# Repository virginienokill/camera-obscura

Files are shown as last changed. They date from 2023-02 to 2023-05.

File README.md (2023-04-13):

# Camera Obscura

### travail en cours

*Camera Obscura* est un projet de théâtre optique itinérant de la Cie Nokill dont la première est prévue pour l'été 2024. 

Sur ce site nous rassemblons au fur et à mesure de la création, tous les contenus artistiques et techniques qui nous sont utiles. 

Même si à la base cette documentation est un outil de travail personnel, nous avons décidé de la mettre à disposition de toute personne intéressée par ce projet.

- [Dossier de création](contenu/dossier/dossier-camera-obscura-2024-web.pdf), télécharger le dossier en pdf.
- [Prototypes](contenu/prototypes), liste des chambres construites pendant la création.
- [Écriture](contenu/ecriture), textes, scenarios, découpages et références.
- [Technique](contenu/technique), questions et réponses concernant les differents défis techniques. 
- [Production](contenu/production.md), partenaires du projet et calendrier des résidences.
- [Bibliographie](contenu/bibliographie.md), liens et documents utiles.
- [Todo](contenu/todo.md), bloc-notes des trucs à faire.
- [Présentation du projet](contenu/presentation-partenaires.md), à l’intention des partenaires techniques et scientifiques.
- [Media](contenu/media.md), liste de tous les media liés à la documentation de la création.

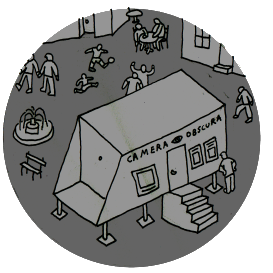
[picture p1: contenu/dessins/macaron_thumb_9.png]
Dessin de la remorque


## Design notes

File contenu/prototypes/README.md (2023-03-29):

# Les prototypes de chambres noires

D'ici, on peut accéder aux fiches des différents protos de chambres noires (camera obscura). On distingue 2 types de réalisations :
- Les chambres individuelles, pour 1 regardeur à la fois (00, 01, 02, 03). Concues au départ pour tester les principes optiques du projet final (05) qui accueillera le spectacle, elles peuvent être disposées dans l'espace public en libre accès.
- Les chambres collectives pour un groupe de regardeurs dont le nombre peut varier de six (04) à vingt (05).

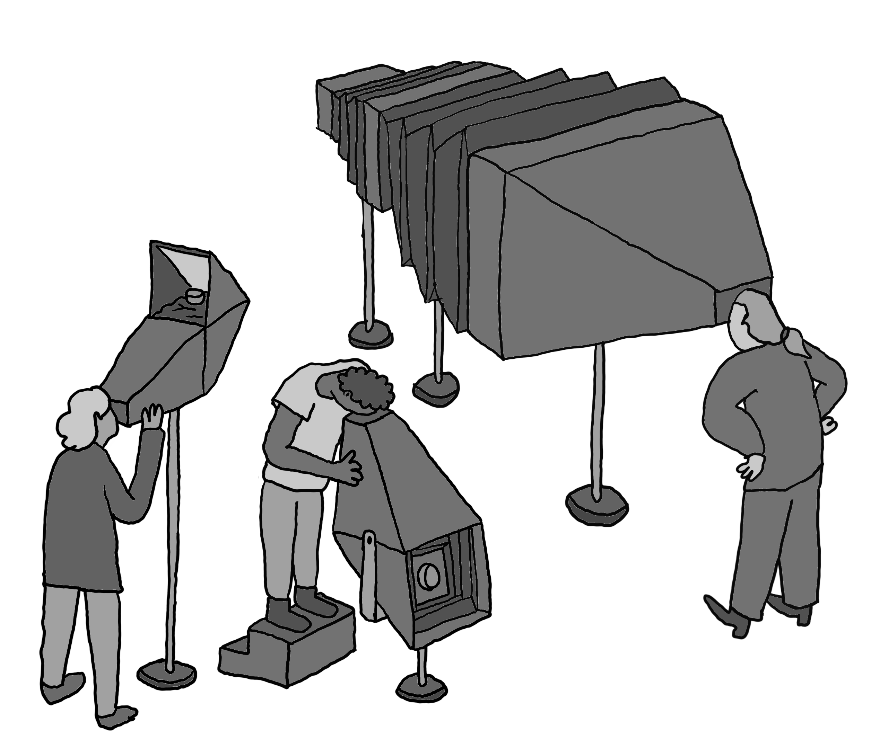
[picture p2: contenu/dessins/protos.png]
dessin de trois prototypes

*De gauche à droite, les cameras 01, 02 et 03*

## Chambres individuelles

- [Camera obscura 00 - Mini camera obscura](camera00.md)
- [Camera obscura 01 - Les yeux dans le dos](camera01.md)
- [Camera obscura 02 - Chambre à antotype](camera02.md)
- [Camera obscura 03 - Chambre grand format](camera03.md)

## Chambres collectives

- [Camera obscura 04 - Chambre sprinter](camera04.md)
- [Camera obscura 05 - Chambre remorque](camera05.md)

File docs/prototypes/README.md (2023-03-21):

Les prototypes de camera obscura
================================

D'ici, on peut accéder aux fiches des différents protos de camera obscura. On distingue 2 types de réalisations :
- Les cameras obscuras individuelles, pour 1 regardeur à la fois (00, 01, 02, 03). Concues au départ pour tester les principes optiques du projet final (05) qui accueillera le spectacle, elle peuvent être disposées dans l'espace public en libre accès.
- Les cameras obscuras collectives pour un groupe de regardeurs dont le nombre peut varier de six (04) à vingt (05).

dessin de trois prototypes
*De gauche à droite, les cameras 01, 02 et 03*

Les Protos
----------

- [Camera obscura 00 - Mini camera obscura](camera00.md)
- [Camera obscura 01 - Les yeux dans le dos](camera01.md)
- [Camera obscura 02 - Chambre à antotype](camera02.md)
- [Camera obscura 03 - Chambre grand format](camera03.md)
- [Camera obscura 04 - Chambre sprinter](camera04.md)

Le Projet final
---------------

- [Camera obscura 05 - Chambre remorque](camera05.md)

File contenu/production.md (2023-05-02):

# Partenaires

Coproducteurs :

- MIMA
- LE PARVIS
- QUAI DES SAVOIRS

Soutiens :

- LE KIWI / ARTO
- LE PERISCOPE
- RUE D'ÉTÉ
- CIRCA
- SCÈNES CROISÉES DE LOZÈRE
- ASSOCIATION DES CLOUS

Interlocuteurices :

- Cie Titanos
- Arnaud Vidal
- Jérémie Dain
- Eric Amblard
- Evelyne Salançon
- Gérard Tayeb
- Juan P. Martínez Pastor 

# Calendrier des résidences

## Résidences passées

### du 7/12/2022 au 14/12/2022 : Graulhet (81) - Nokill
- construction maquette "les yeux dans le dos"
- début construction chambre à anthotypes

### du 2/3/2023 au 4/3/2022 : Graulhet (81) - Nokill
- finitions chambre à anthotype
- début construction chambre grand format
- début construction double miroir

### du 6/3/2023 au 8/3/2022 : Toulouse (31) - QDS
- Améliorations protos
- Recherches autour du soufflet
- Documentation des protos
- Tests en extérieur

### du 1/4/2023 au 6/4/2023 : Graulhet (81) - Chez Pons et au Fablab de la MJC de Graulhet

- construction soufflets des cameras 2 et 3
- construction du prisme de miroirs en toit d'Amici
- début construction camera 4
- prise de contact avec le Fablab d'Airbus 
- Amélioration cameras 1 et 2
- Construction camera 3
- Tests en extérieur
- Documentation vidéo avec Mathieu

## Résidences à venir

### du 9/5/2023 au 12/5/2023 : Toulouse (31) - QDS
- Rencontre Airbus ?

### du 10/6/2023 au 18/6/2023 : Mirepoix (09) - Mima
- test camion

### en juillet 2023 (du 11 au 13 ou du 25 au 27) : Ramonville (31) - Arto
- test camion

### en été 2023 : Graulhet (81) - Nokill ou Marseille (13) - Nokill
- plans remorque 

### en automne 2023
Maxeville (Michto) ou accueil en Occitanie. 
- construction remorque

### du 30/10/2023 au 5/11/2023 : Assier (46) - Des clous
- écriture et aménagement remorque

### fin hiver/printemps 2024 (du 15 au 26 avril) : Auch (32) - Circa
- écriture et jeu

### printemps 2024 : Mende (48) - Scènes croisées de Lozère
- écriture et mise en scène

### printemps 2024 : Nimes (30) - Périscope
- écriture et mise en scène
- "Un atelier collectif autour de la création d'un court film qui utilise certaines des techniques en jeu dans la création en cours Camera Obscura. Les techniques en question se situant quelque part entre papier decoupé, théâtre d'ombre et lanterne magique."
### Juin juillet 2024 : Tarbes (65) - Le Parvis
- mise en scène

### du 23/7/2024 au 1/8/2024, Mirepoix (09) - Mima
- Finitions

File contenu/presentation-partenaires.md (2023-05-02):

# Camera Obscura
#### Fiche de présentation à l'intention des partenaires techniques et scientifiques.

*Camera Obscura* est un projet de théâtre optique itinérant dont la première est prévue pour l'été 2024.

<div style="display:flex;flex-direction:row;flex-wrap:wrap;">
illustration camera obscura
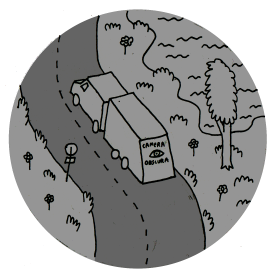
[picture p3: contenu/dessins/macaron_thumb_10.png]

</div>

## En résumé

Une salle de cinéma est posée dans l'espace public, une vingtaine de spectateurs s'y installent, la salle est plongée dans le noir et le public assiste à la projection d'un court-métrage d'une vingtaine de minutes.

La particularité de ce film est qu'il est produit sans pellicule, ni vidéo, ni électricité, et qu'il n'utilise comme énergie que celle du soleil et des comédiens.

<div style="display:flex;flex-direction:row;flex-wrap:wrap;">
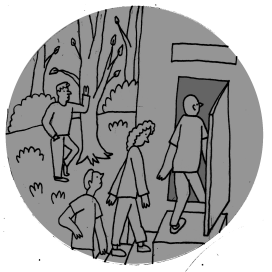
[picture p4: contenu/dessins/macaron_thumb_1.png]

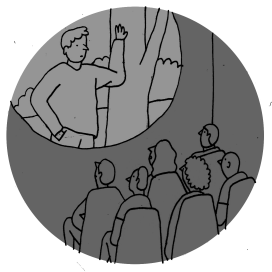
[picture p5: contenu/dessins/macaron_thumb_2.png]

</div>

Les images sont des captations du monde extérieur qui transitent par un dispositif optique fait d'objectifs, de prismes et de miroirs. Les sons et la musique sont produits et interprétés en direct grâce à un ensemble d'instruments acoustiques et mécaniques.

L’enjeu principal de cette création est donc de créer l’illusion de la projection d’un film et de reproduire les codes et les formes du cinéma, sans en utiliser la technologie.

Cette démarche s'inscrit à la fois dans une idée de sobriété énergétique et dans la volonté de créer une esthétique et une expérience unique.

## Défis techniques

Ce projet s'accompagne d'un grand nombre de défis techniques dans des domaines variés :
- Comment afficher une image [lumineuse](technique/luminosite.md) de [grande dimension](technique/calage.md) sans autre source de lumière que le soleil dans un véhicule transformé en salle de cinéma itinérante ?
- Comment [redresser une image](technique/renversement.md) naturellement renversée par son passage à travers un objectif ?
- Comment maintenir une [température supportable](technique/isolation.md) et assurer un renouvellement de l'air dans une remorque exposée au soleil sans apport extérieur d'énergie ?
- Comment servir des popcorns aux spectateurs, sans utiliser ni gaz ni électricité pour les cuire ?
- Comment donner l'[illusion d'un son "cinéma"](technique/son.md) en se limitant à des systèmes acoustiques ?
- Comment construire une [salle de cinéma](prototypes/camera05.md) légère, durable, compacte et mobile adaptée à l'accueil du public ?

Pour relever ces défis, nous cherchons activement des partenaires : des interlocuteurs pour la conception, mais aussi des lieux et des moyens de fabrication, et des circuits d'achat ou de récupération de matériel.

<div style="display:flex;flex-direction:row;flex-wrap:wrap;">
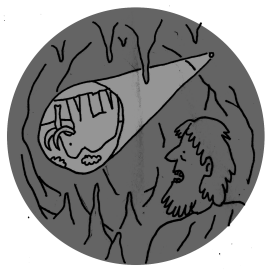
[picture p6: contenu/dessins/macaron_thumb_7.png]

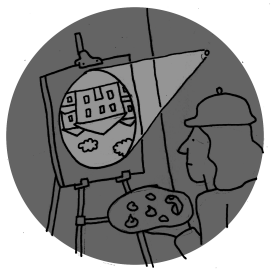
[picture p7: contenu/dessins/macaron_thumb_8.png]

</div>

## La compagnie Nokill

*Camera Obscura* sera le cinquième spectacle de notre compagnie. Dans les spectacles précédents dont les teasers et les descriptions sont disponibles sur [le site de la compagnie Nokill](http://cienokill.fr/), nous convoquons régulièrement sur scène des dispositifs techniques qui nous servent de supports pour raconter des histoires, des robots dans [*Turing Test*](http://turing-test.cienokill.fr/), des machines pré-cinématographiques dans [*L'Envol*](http://cienokill.fr/spectacles/lenvol/), des hologrammes dans [*Elektra*](http://cienokill.fr/spectacles/elektra/). *Camera Obscura* s'inscrit dans la continuité de cette démarche.

## La documentation du spectacle

Comme nous avons eu l'occasion de le faire pour [*Turing Test*](http://turing-test.cienokill.fr/), nous documentons l'intégralité du processus de création sur [un site dédié à *Camera Obscura*](https://camera-obscura.cienokill.fr/), vous pourrez y trouver du contenu concernant les différents aspects du spectacle (technique, artistique, production). Nous sommes aussi disponibles pour échanger [par mail](http://cienokill.fr/contact/) ou en visio, pour répondre à vos questions et vous parler du projet plus en détail.

<div style="display:flex;flex-direction:row;flex-wrap:wrap;">
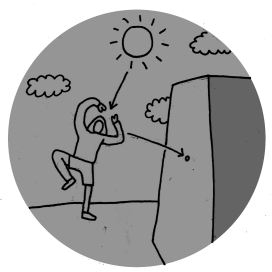
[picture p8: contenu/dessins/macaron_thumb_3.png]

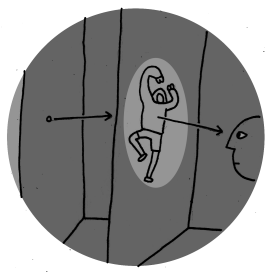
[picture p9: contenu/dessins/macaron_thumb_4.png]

</div>

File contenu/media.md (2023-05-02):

# Media

Cette page rassemble tous les medias liés à la documentation de la création. Ce sont les images, vidéos, etc. utilisées dans les différentes pages du site.

# Vidéos

Les vidéos sont hébergées sur Vimeo et rassemblées dans [un showcase nommé Camera Obscura](https://vimeo.com/showcase/10324493)

<div style='padding:56.25% 0 0 0;position:relative;'>
    <iframe src='https://vimeo.com/showcase/10324493/embed' allowfullscreen frameborder='0' style='position:absolute;top:0;left:0;width:100%;height:100%;'></iframe>
</div>

# Images

Les images sont réparties dans 4 dossiers. Elles sont hébergées sur le git. Les images en bitmap (non vectorielles) sont compressées pour alléger le site.

## Photos

le dossier [`photos/`](https://github.com/LeonLenclos/camera-obscura/tree/main/contenu/photos) contient les photos prises pendant la création.

{% include gallery.html folder="/contenu/photos/" %}

## Plans

le dossier [`plans/`](https://github.com/LeonLenclos/camera-obscura/tree/main/contenu/plans) contient les dessins techniques, patrons et plans utiles pendant la création.

{% include gallery.html folder="/contenu/plans/" %}

## Dessins

le dossier [`dessins/`](https://github.com/LeonLenclos/camera-obscura/tree/main/contenu/dessins) contient les dessins non-techniques et les illustrations.

{% include gallery.html folder="/contenu/dessins/" %}

## Img

le dossier [`img/`](https://github.com/LeonLenclos/camera-obscura/tree/main/contenu/img) contient toutes les images qui n'entrent pas dans les catégories précédentes, notamment les gif animés et les montages photos.

{% include gallery.html folder="/contenu/img/" %}

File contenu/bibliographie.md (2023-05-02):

# Liens

## Théorie

- [Schema interactifs d'optique géométrique](https://phyanim.sciences.univ-nantes.fr/optiqueGeo/index.php)
- [chaîne youtube de photo avec pas mal de contenus intéressants](https://youtube.com/@PhotoGraal)
- [geogebra](https://www.geogebra.org/calculator/hahmryyn)
- [logiciel (payant) pour créer des optiques](https://www.zemax.com/)
- [bouquins théoriques](https://www.babelio.com/livres/Houard-Optique/898680)

## Gramophone

- [Vidéo à propos du HMV 102](https://www.youtube.com/watch?v=AYn7aZZBMRA)

## Soufflets

- [Tuto détaillé général](https://www.galerie-photo.com/construire-soufflet-chambre-photo.html)
- [Tuto plus précis](http://www.disactis.com/soufflet/soufflet.php)
- [Tuto de monsieur Smets](https://docplayer.fr/12405417-Fabriquez-votre-soufflet.html)
- [Article de blog avec photos HD d'un vieux soufflet](https://delalumieredanslatelier.blogspot.com/2019/06/appareil-photo-soufflet-marque-nagel-n.html)

## Animation 

- [Terry Gilliam, cutout anim](https://youtu.be/KOqcHCEqO1k)

## Photo très grand format

- [Article sur des photographes très grand format](https://fstoppers.com/diy/photographer-creates-gigantic-ultra-large-format-digital-camera-571295)
- [Article de blog sur l'ultra-grand format](https://photographylife.com/ultra-large-format-cameras)
- [Définition de process lens discutée sur un forum de photo](https://www.photo.net/forums/topic/48909-what-is-a-process-lens/)
- [John Chiara photographe qui a une CO remorque pour faire du très grand format](https://www.johnchiara.com/films)

## Objectifs très grands formats / process lens

- [Doc technique détaillée sur les objectifs grands formats de Rodenstock](http://www.dmin-dmax.fr/chambre/archives_techniques/rodenstock_2000.html)

## Sténopé 

- [Tuto détaillé sur la photo au sténopé](https://galerie-photo.com/stenope.html)
- [Video stenopé numérique](https://www.youtube.com/watch?v=yWew2kOWTiA)

## Papier inversible 

- [Discussion autour du papier inversible sur un forum de photo ](http://www.galerie-photo.info/forumgp/read.php?3,239522)
- [DIRECT POSITIVE PAPER harman chez Ilford](https://www.ilfordphoto.com/harman-direct-positive-paper-roll)
- [direct positiv paper, différentes refs (eshop)](https://www.macodirect.de/en/paper/direct-positive-papers/)

## Camera obscura

- [Camera Obscura & World of Illusions , un musée à Édinburgh](https://www.camera-obscura.co.uk/attractions/the-camera-obscura)
- [Site très riche à propos de la CO par un restaurateur/créateur de CO](http://www.camera-obscura.org.uk/Camera_Obscura/Welcome.html)
- [Thomas Mezzanotte, artiste ayant notamment construit une CO dans une sorte de tente](https://thomas-mezzanotte.squarespace.com/)
- [Double CO sur un bateau sur le danube](https://olafureliasson.net/artwork/camera-obscura-fuer-die-donau-2004/)
- [CO sur une plage vers San Fransisco](https://youtu.be/qvwpDIlN25o)

## Miroirs caustiques

- [Rayform, fabriquant de miroirs caustiques](https://rayform.ch/)
- [Vidéo à propos des miroirs caustiques de rayform](https://www.youtube.com/watch?v=wk67eGXtbIw)

## True mirrors

- [Prisme en toit d'Amici](https://fr.wikipedia.org/wiki/Prisme_en_toit_d%27Amici)
- [La boutique](https://store.truemirror.com/)
- [La vidéo où le createur dit qu'il utilise des first surface mirror](https://www.youtube.com/watch?v=oHeOf9MZ49o)
- [la vidéo du mec là](https://www.youtube.com/watch?v=x2owiSx0biU)

## First surface mirror

- [How to Make a Front Surface Mirror (Quick & Easy Techniques)](https://medium.com/geekculture/how-to-make-a-front-surface-mirror-quick-easy-techniques-c1ba3ecf6347)
- [FSM (Fournisseur)](https://firstsurfacemirror.com/)

## prismes

- [tuto prisme eau ](https://www.instructables.com/Optical-Water-Prism/)

## Lanternes magiques

- [Lanternes magiques](https://en.wikipedia.org/wiki/Magic_lantern)
- [petit Doc en anglais](https://youtu.be/w1XkqtzLfKo)

## Historique

- [Objectif de CO avec prisme intégré 18e sciècle :](http://www.niepce-daguerre.com/objectif_de_camera_obscura.html)

## Antotypes

- [Anthotypes: explore the darkroom in your garden - Le livre de ref](http://leonlenclos.net/pro/pirate/anthotypes-explore-the-darkroom-in-your-garden-and-make-photographs-using-plants-1466261005-9781466261006_compress.pdf)
- [Recette à base d'épinard](http://wiki.scienceamusante.net/index.php/Les_anthotypes)
- [Le végétal est photographie (Mémoire)](https://www.esam-c2.fr/IMG/UserFiles/docs/memoires/2017_pelletier_marieve.pdf)
- [Mary Somerville, inventeuse oubliée de l'anthotypie ](https://en.wikipedia.org/wiki/Mary_Somerville)

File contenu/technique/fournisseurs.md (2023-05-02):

## Optiques, objectifs, prismes, verre

- [Camley](www.camleyphotographic.com/)
- [Coprover](https://www.coprover.fr/)
- [bonfoton](https://bonfoton.com/products/bonfoton-camera-obscura-lens)
- [amazing camera obscura](http://www.amazingcameraobscura.co.uk/shop.htm)
- [truemirror](https://store.truemirror.com/collections/all?page=1)
- [bohroptics](http://bohroptics.com/en)

## Ecran, tissus, tulle
- [Showtex](https://www.showtex.com/fr/produits/ecrans-de-projection?page=1)
- [Teviloj](https://www.azur-scenic.com/produit/retro-translucide-depoli/)

## Carton
- [hermet](https://www.hermet.fr/)

## Peinture
- [adaptaville](https://www.adaptaville.fr/peinture-anti-chaleur-toit)

## Remorque
- [rouergue-remorque](https://www.rouergue-remorque.com/remorque/remorque-bw-tiny-house-ch-600-2/)

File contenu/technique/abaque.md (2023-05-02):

Pour le Apo-Nikkor 610mm posé contre la vitre à l'intérieur de la CO

| Distance Objet-Vitre | Distance Vitre-Image |
|---|---|
| 70 cm | 320 cm |
| 100 cm | 155 cm |
| 200 cm | 91 cm |
| 800 cm | 70 cm |
| infini | 68 cm |

Pour le Rotenstock 360mm posé contre la vitre à l'intérieur de la CO

| Distance Objet-Vitre | Distance Vitre-Image |
|---|---|
| 40 cm | 172 cm |
| 70 cm | 72 cm |
| 100 cm | 57 cm |
| 200 cm | 46 cm |
| 800 cm | 41 cm |
| infini | 39 cm |

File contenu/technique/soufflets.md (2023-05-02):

# Les soufflets

Pour effectuer la mise au point et lorsque l'on change de focale, il faut changer la distance entre l'écran et l'optique.
Or, quelque soit la position de l'optique par rapport à l'écran, il faut que la chambre reste hermétique à la lumière.

Pour concilier étanchéité du dispositif et possibilité varier la position relative des deux parties,
la solution traditionnellement utilisée pour les chambres noires photographiques (mais aussi pour les accordéons et les autobus articulés) est celle du soufflet.

Bien que le choix du soufflet vienne apporter une solution très satisfaisante au problème décrit ci-dessus, il apporte aussi son lot de soucis :
- Le patron d'un soufflet est difficile à dessiner.
- Le choix des matériaux est délicat (robustesse, souplesse, étanchéité, couleur)
- La construction d'un soufflet est chronophage.

<div style="padding-bottom: 56.25%; max-width: 100%; position: relative;"><iframe src="https://player.vimeo.com/video/816255116?title=0&portrait=0&byline=0" width="800px" height="450px" style="position: absolute; top: 0px; left: 0px; width: 100%; height: 100%;" frameborder="0"></iframe></div>

*Timelapse de la construction d'un soufflet pour la [camera 03](../prototypes/camera03.md)*

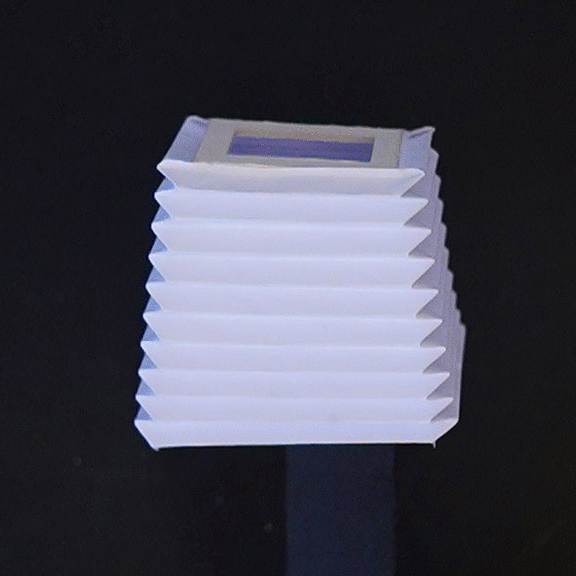
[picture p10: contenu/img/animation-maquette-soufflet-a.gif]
animation maquette soufflet

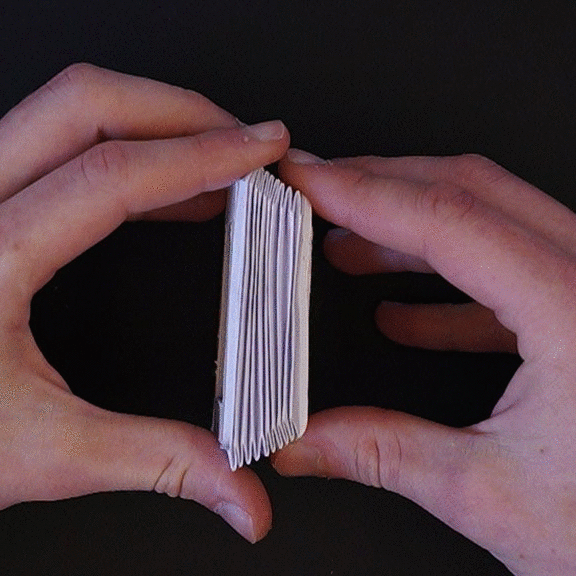
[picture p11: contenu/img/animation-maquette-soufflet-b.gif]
animation maquette soufflet


*Maquette de soufflet en papier*

## Processus de fabrication

### Dessiner un soufflet

On s'intéresse ici à la construction de soufflets "coniques" et "rectangulaires".

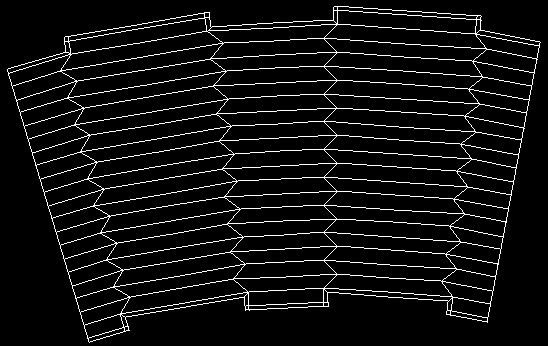
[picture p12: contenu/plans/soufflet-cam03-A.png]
patron d'un soufflet


*Exemple de patron d'un soufflet*

### Préparation

Choix à faire avant de commencer :

- taille du grand cadre
- taille du petit cadre (côté objectif)
- largeur des plis
- nombre de plis
- La manière dont le soufflet est collé au grand cadre et au petit cadre.

Pour la largeur des plis on choisit en général 100mm ou 50mm. Puisque le soufflet est conique les plis mesureront une fois sur deux un peu plus et une fois sur deux un peu moins que la valeur choisie. Cette valeur est néanmoins très importante pour dessiner le soufflet.

Le nombre de plis déterminera la longueur du soufflet minimum et maximum.

Dans le cas d'un soufflet très peu conique la longueur du soufflet ouvert au max sera environ `nombre de plis × largeur des plis × 1/2`

La longueur du soufflet fermé au max sera environ `nombre de plis × épaisseur du carton × 2.5`

Pour coller le soufflet à son support, trois solutions :

1. Coller à l'extérieur du cadre
2. Coller à l'intérieur du cadre
3. Coller à plat

**Attention : il est possible qu'une erreur se soit glissée dans les instructions concernant les collages 2 et 3**

Sur le dessin ci-dessous la longueur représentée par la flèche désigne ce qu'on appelle la taille du cadre. N.b. selon la manière de coller, ce que l'on désigne par taille du cadre peut faire référence à l'intérieur du soufflet (rectangle à travers lequel on regarde) ou faire référence à l'extérieur du soufflet (encombrement du soufflet quand il est plié)

schema collage soufflet

### Dessin

On va d'abord dessiner une arête du soufflet (un quart du soufflet) puis la dupliquer en appliquant des symétries axiales pour avoir le soufflet complet.

#### Tracer le pli en zigzag de l'arête

On commence par tracer deux traits verticaux espacés de la largeur d'un pli puis on trace un zigzag entre ces deux traits avec des angles de 90°. Ce zigzag a autant de sommets qu'il y aura de plis.

#### Tracer la médiane du pan de gauche

Soit C et D les deux extrémités du zigzag.

Tracer un cercle de centre C.
Si le trait du zigzag qui part de C va vers la gauche, le diamètre du cercle est : *1/2 × longueur du **petit** côté du **petit** cadre + largeur des plis*.
Sinon le diamètre est *1/2 × longueur du **petit** côté du **petit** cadre*.

Tracer un cercle de centre D.
Si le trait du zigzag qui part de D va vers la gauche, le diamètre du cercle est *1/2 × longueur du **petit** côté du **grand** cadre + largeur des plis*.
Sinon le diamètre est *1/2 × longueur du **petit** côté du **grand** cadre*

La médiane du pan de gauche est la tangeante extérieure à ces deux cercles qui passe à gauche des cercles. On la note droite d.

#### Tracer les plis du pan de gauche

Soit C' l'intersection de cette droite avec le cercle de centre C et D' l'intersection de cette droite avec le cercle de centre D.

les segments CC' et DD' sont le premier et le dernier pli du pan. CC' et DD' sont parallèles.

Tous les autres plis du pan peuvent désormais être tracés, ce sont les segments parallèles à CC' par chaque sommet du zigzag. on fait aller ces segments des sommets du zigzag à la droite d.

#### Reproduire ces étapes pour le pan de droite

Pour la médiane du pan de droite reproduire ces étapes symétriquement, mais en prenant en compte les longueurs des **grands** côtés des cadres.

#### Tracer les languettes aux extremités du soufflet.

pour la jonction cadre-soufflet se référer à ce [schema](/contenu/plans/collage-soufflet-patrons.png) en fonction de ce que l'on choisit comme manière de coller le soufflet au cadre. (En vert les plis extérieurs en cyan les plis intérieurs)

#### Dupliquer le tracé 

tracer la symétrie du dessin par la médiane du côté de gauche (droite d).

Puis tracer à nouveau la symétrie du dessin ainsi obtenu par la médiane du côté de droite.

## Construire un soufflet

Le soufflet sera réalisé avec un sandwich tissu-carton-skaï :
- Du tissu noir à l'intérieur
- Du carton 1mm pour la rigidité.
- Du skaï blanc à l'extérieur pour la fraicheur et l'étanchéité.

Le carton est coupé à la découpeuse laser : on creuse une gouttière de 2.5mm entre chaque pan et on laisse un petit raccord de 2.5mm tous les 200mm pour conserver la forme sans gêner le pliage.

La découpeuse laser du FabLab de Graulhet nous permet de découper des plaques en carton de 1000x700mm

Les fichiers pour la découpe seront fournis au format dxf.

Le sandwich est collé à la colle à reliure, temps de séchage = 24h.

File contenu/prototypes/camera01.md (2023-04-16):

#  Les Yeux Dans Le Dos

| prototype n° | 01 |
|---|---:|
| nom vernaculaire | Les Yeux Dans Le Dos |
| début construction | décembre 2022 |
| nombre de spectateur·ices | 1 |
| taille de l'image | 30×30 cm |
| distance de tirage min-max  | ? |
| dimensions exterieures | ? |
| objectif monté | Process lens Zeiss S-TESSAR 5,6/300 |

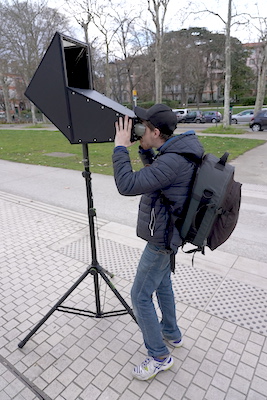
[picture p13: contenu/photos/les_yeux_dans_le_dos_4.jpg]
les_yeux_dans_le_dos_4


[une vidéo de test des Yeux dans le dos :](https://vimeo.com/cienokill/cameraobscura-proto01)

<div style="padding-bottom: 56.25%; max-width: 100%; position: relative;"><iframe src="https://player.vimeo.com/video/809841929?title=0&portrait=0&byline=0" width="800px" height="450px" style="position: absolute; top: 0px; left: 0px; width: 100%; height: 100%;" frameborder="0"></iframe></div>

## Description générale
En regardant à l'intérieur de cette camera obscura, on découvre une image à l'endroit d'environ 30 cm x 30 cm de ce qui est derrière nous.

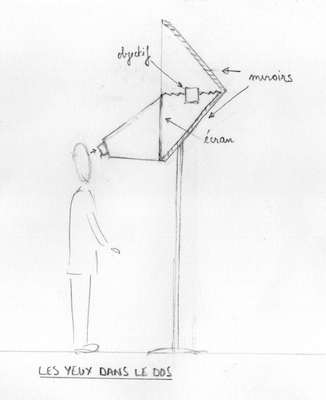
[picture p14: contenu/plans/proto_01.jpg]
proto_01

## Allure
Une boite noire de forme complexe est fixée sur un pied de projecteur. À hauteur d'yeux on trouve un viseur en forme de lunettes de protection.

## Matériaux
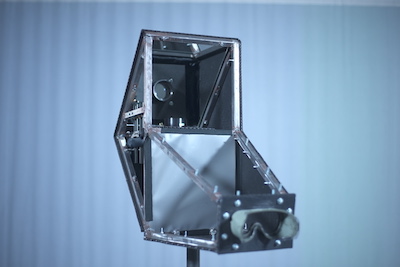
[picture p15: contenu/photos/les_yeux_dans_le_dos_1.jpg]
les_yeux_dans_le_dos_1


### Chassis
- Tube d'acier soudé (20 mm x 20 mm).

### Parois
- Panneau de plastique alvéolaire

### Écran
- Toile de rétroprojection (translucide/dépoli) tendue sur cadre acier

### Objectif
- Process lens Zeiss S-TESSAR 5,6/300

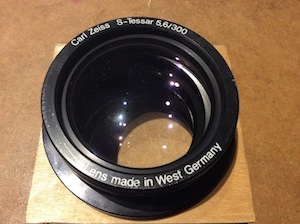
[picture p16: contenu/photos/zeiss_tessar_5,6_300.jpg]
zeiss_tessar_5,6_300


### accessoires
- L'objectif fixé sur un clamp coulisse sur 2 rails
- Un soufflet en tissu fixé entre la planchette et le chassis maintient l'obscurité.

## Évaluation des avantages et des inconvénients

### Avantages
- image très claire
- à l'endroit

### Inconvénients
- image relativement petite
- axe inversé

## Améliorations envisagées
- déport de point à l'extérieur pour faciliter le reglage de la position de l'objectif sur le rail.
- vitre de protection et pare-soleil pour protèger les miroirs et l'objectif.

## Moment envisagé pour la construction et/ou les améliorations
printemps 2023

## Détails de construction et description technique

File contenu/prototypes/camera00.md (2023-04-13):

#  Mini Camera obscura

| prototype n° | 00 |
|---|---:|
| nom vernaculaire |  Mini camera obscura |
| début construction | mars 2023 |
| nombre de spectateur·ices | 1 |
| taille de l'image | 4×4 cm |
| distance de tirage min-max  | ? |
| dimensions exterieures | ? |
| objectif monté | Helios 44-2 / 2/58mm |

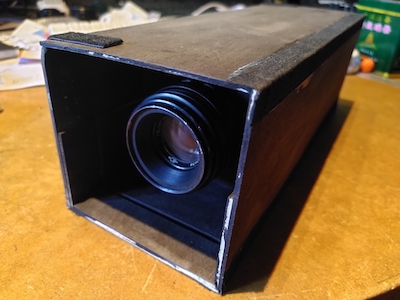
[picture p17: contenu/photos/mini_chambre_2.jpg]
mini_chambre_2


## Description générale
En regardant à l'intérieur de cette camera obscura, on découvre une image à l'endroit d'environ 4 cm x 4 cm de ce qui est devant nous.

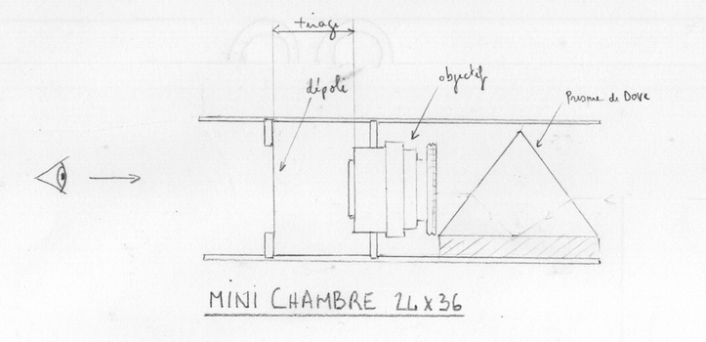
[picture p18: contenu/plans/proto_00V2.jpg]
proto_0


## Allure
Une boite noire de forme parallélépipédique. L'image est projetée sur un dépoli à l'arrière du tube. Un prisme de Dove est placé devant l'objectif.

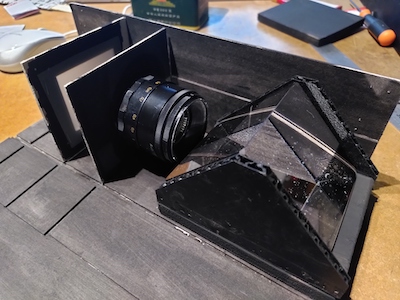
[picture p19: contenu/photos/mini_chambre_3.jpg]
mini_chambre_3

## Matériaux

### Parois
- Carton-bois

### Écran
- Toile de rétroprojection (translucide/dépoli) tendue sur cadre acier

### Objectif
- objectif 24x36 monture M42 (Helios 44-2 / 2/58mm) 

### Accessoires
- L'objectif et le dépoli sont fixés sur des planchettes maintenues dans des rigoles.

## Évaluation des avantages et des inconvénients

### Avantages
- très léger
- parfait pour des tests

### Inconvénients
- image petite et tronquée
## Améliorations envisagées

## Moment envisagé pour la construction et/ou les améliorations
printemps 2023

## Détails de construction et description technique

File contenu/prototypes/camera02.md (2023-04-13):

#  Chambre à Antotype

| prototype n° | 02 |
|---|---:|
| nom vernaculaire | Chambre à Antotype |
| début construction | décembre 2022 |
| nombre de spectateur·ices | 1 |
| taille de l'image | 50×50 cm |
| distance de tirage min-max  | environ 35-55cm |
| dimensions exterieures | ? |
| objectif monté | Process lens APO RONAR RODENSTOCK 9/360 mm |

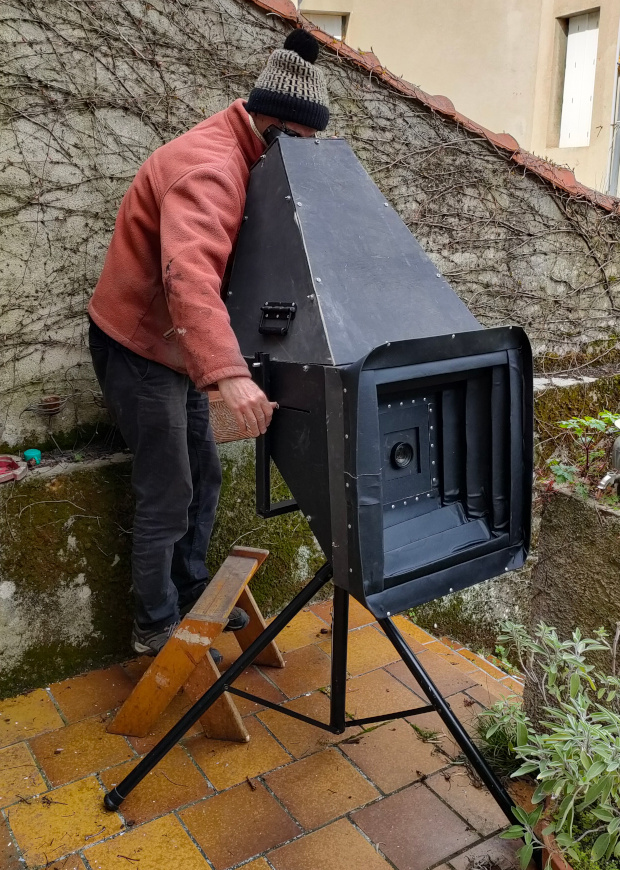
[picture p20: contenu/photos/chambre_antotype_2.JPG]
chambre_anthotype_1


## Description générale

En regardant dans le viseur situé au dessus de cette camera obscura, on découvre une image à l'endroit d'environ 50 cm x 50 cm de ce qui est devant nous.

L'écran est amovible et peut être remplacé par une plaque sur laquelle on aura disposé un papier photo-sensible type antotype.

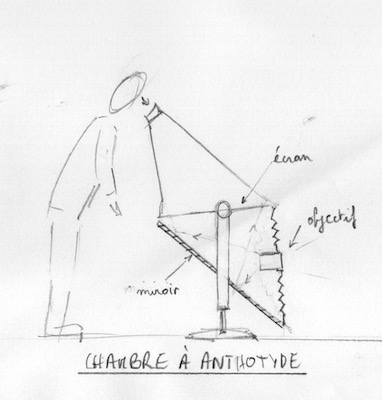
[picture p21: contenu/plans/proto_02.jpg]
proto_02


## Allure

Une boite noire de forme complexe est fixée sur un pied de projecteur. La forme évoque les chambres moyen-format type rolleiflex. Sur le dessus, on trouve un viseur en forme de lunettes de protection. À l'avant, un soufflet en skaï noir.

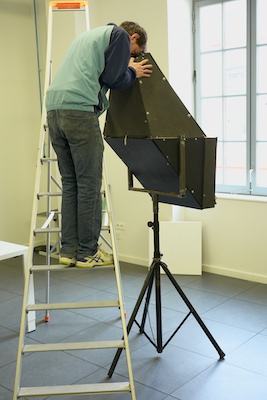
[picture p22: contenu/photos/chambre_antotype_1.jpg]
chambre_anthotype_1


## Matériaux

### Chassis
- Tube d'acier soudé (20 mm x 20 mm).

### Parois
- Panneau de plastique alvéolaire et contreplaqué 5 mm

### Écran
- Toile de rétroprojection (translucide/dépoli) tendue sur cadre acier

### Objectif
- Process lens APO RONAR RODENSTOCK 9/360 mm

### Accessoires
- La planchette de l'objectif est montée sur un rail Igus. Sur le côté exterieur de la chambre, une vis permet de régler la mise au point en entrainant la planchette.
- Un soufflet entre la planchette et le chassis maintient l'obscurité dans la boite.

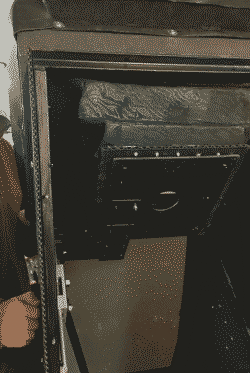
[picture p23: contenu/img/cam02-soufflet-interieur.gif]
animation soufflet


*Vue interieur du mécanisme de réglage de mise au point*

## Évaluation des avantages et des inconvénients

### Avantages
- image dans l'axe
- à l'endroit

### Inconvénients
- visée par le dessus
- peu clair

## Améliorations envisagées
- peinture du chassis
- vitre de protection et pare-soleil
- fixation des lunettes
- achat objectif plus lumineux

## Moment envisagé pour la construction et/ou les améliorations
printemps 2023

## Détails de construction et description technique

cotes proto02

### Soufflet

- [Patron soufflet en dxf](/contenu/plans/soufflet-cam02.dxf)
- [Patron soufflet en pdf pour aperçu](/contenu/plans/soufflet-cam02.pdf)

cotes :

- Grand cadre : 528mm x 488mm (collage interieur)
- Petit cadre : 220mm x 220mm (collage contre)
- Largeur plis : 50mm
- nombre de plis : 10

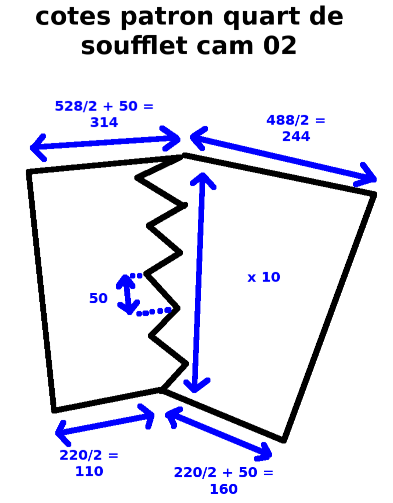
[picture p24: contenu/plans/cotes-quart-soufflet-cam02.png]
cotes soufflet


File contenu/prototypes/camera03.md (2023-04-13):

#  Chambre grand format

| prototype n° | 03 |
|---|---:|
| nom vernaculaire | Chambre grand format |
| début construction | mars 2023 |
| nombre de spectateur·ices | 1 |
| taille de l'image | 100×73 cm |
| distance de tirage min-max  | ? |
| dimensions exterieures | ? |
| objectif monté | Process lens NIKON APO NIKKOR 9/610mm |

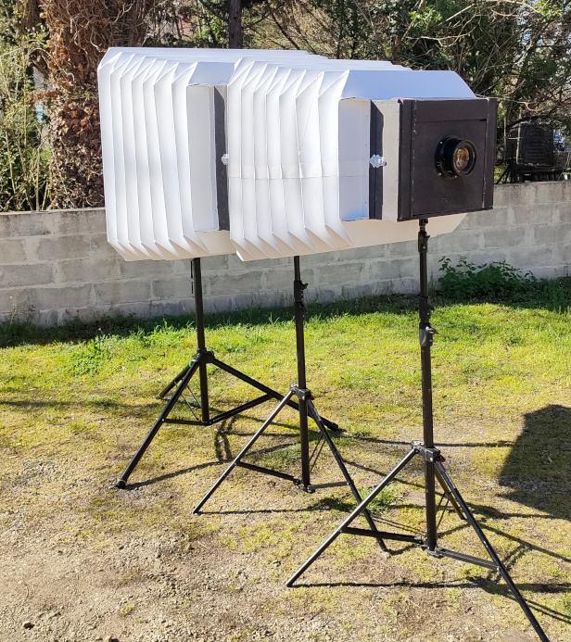
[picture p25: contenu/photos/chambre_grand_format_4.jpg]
chambre_grand_format


## Description générale

En regardant dans le viseur situé à l'arrière de cette camera obscura, on observe une image à l'envers d'environ 100 cm x 73 cm (format 1,37) de ce qui est devant nous.

chambre_grand_format

## Allure

Une boite noire de forme pyramidale couchée, fixée sur un pied de projecteur fait office de viseur de champ. Elle est prolongée par un long soufflet blanc construit en deux parties et se termine par le support de l'objectif, lui-même fixé sur un pied. La forme évoque les chambres photographiques ultra grand format. Un pied intermédiaire limite l'affaissement du soufflet.

proto_03

## Matériaux

### Chassis
- Tube d'acier soudé (20 mm x 20 mm).

### Parois
- Contreplaqué 5 mm

chambre_grand_format

### Écran
- Toile de rétroprojection (translucide/dépoli) tendue sur cadre bois

### Objectif
- Process lens NIKON APO NIKKOR 9/610mm

apo_nikkor_9_610mm_2

### Accessoires

- Pour retourner l'image, il est envisagé d'utiliser un prisme en toit d'Amici, fabriqué avec 2 miroirs à 90°.

## Évaluation des avantages et des inconvénients

### Avantages
- image dans l'axe
- grand format
- grande amplitude de réglage du tirage

chambre_grand_format

### Inconvénients
- encombrement
- à l'envers

## Améliorations envisagées

- fabrication et fixation soufflet carton/tissu/cuir
- peinture du chassis

## Moment envisagé pour la construction et/ou les améliorations
printemps 2023

## Détails de construction et description technique

cotes proto02

### Soufflet

chambre_grand_format_1

- [Patron soufflet A en dxf](/contenu/plans/soufflet-cam03-A.dxf)
- [Patron soufflet A en pdf pour aperçu](/contenu/plans/soufflet-cam03-A.pdf)
- [Patron soufflet B en dxf](/contenu/plans/soufflet-cam03-B.dxf)
- [Patron soufflet B en pdf pour aperçu](/contenu/plans/soufflet-cam03-B.pdf)

Grand Soufflet :

- Grand cadre : 1000mm x 733mm (collage exterieur)
- Petit cadre : 740mm x 540mm (collage exterieur)
- Largeur plis : 100mm
- nombre de plis : 16

Petit Soufflet : 

- Grand cadre : 740mm x 540mm (collage exterieur)
- Petit cadre : 456mm x 373mm (collage exterieur)
- Largeur plis : 100mm
- nombre de plis : 16

cotes soufflet
cotes soufflet

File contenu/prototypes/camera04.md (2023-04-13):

#  Chambre Sprinter

## Description générale
Un vehicule type Sprinter Mercedes est transformé en camera obscura en adaptant l'arrière du véhicule pour qu'il accueille un système soufflet/objectif. Un cadre sur lequel est fixé l'écran de 1,80 m x 1,31 m (format 1,37) est installé à l'intérieur du camion. 6 personnes peuvent visionner simultanément l'image.

## Allure
Un utilitaire avec un soufflet qui dépasse à l'arrière.

proto_04

## Matériaux

### Chassis
- Sprinter Mercedes

### Écran
- Toile de rétroprojection (translucide/dépoli) tendue sur cadre

### Objectif
- Process lens Wray Lustrar 16/1075mm Apo

wray_lustrar_16_1075mm_1

### Accessoires
- Pour retourner l'image, il est envisagé d'utiliser un prisme en toit d'Amici, fabriqué avec 2 miroirs à 90°.

## Évaluation des avantages et des inconvénients

### Avantages
- image dans l'axe
- ultra grand format

### Inconvénients
- à l'envers

## Améliorations envisagées

## Moment envisagé pour la construction et/ou les améliorations
printemps 2023

## Détails de construction et description technique
cotes proto02

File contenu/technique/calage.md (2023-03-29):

## Calage des éléments optiques
Les dimensions limitées de la remorque nous imposent un léger gradinage (20 cm par rang) et une rétroprojection. C'est avec cette configuration que nous obtenons le meilleur confort de vision pour une taille de remorque raisonnable.

### Contraintes liées au spectacle
- Nous aurions aimé une distance entre objectif et écran d'au minimum 1 m pour des raisons pratiques d’implantation de l’écran dans la remorque et de positionnement du comédien/opérateur qui est à l'intérieur. 

- Nous visons une taille d’image de 2 m de diamètre ce qui nous permet de cadrer sur un écran de 1,80 m x 1,31 m (1.37) sans trop de vignettage.

### Choix des objectifs
- Nous aimerions utiliser plusieurs objectifs avec des focales différentes, voire des renvois d’angle, et alterner leur usage avec un système de caches manuels afin de reproduire l’illusion d’un montage type cinéma où plusieurs plans différents s’enchaînent. Il faudrait donc trouver le moyen de rendre compatible l'utilisation de ces différents objectifs, en particulier le tirage et la taille des images obtenues.

### liste des objectifs en notre possession :

- Process lens Wray Lustrar 1060 mm - F16

- Process lens Nikon APO Nikkor 610 mm - F9

- Process lens Ilex Paragon 380 mm - F9 

- Process lens Apo Ronar Rodenscock 360 mm - F9

- Process lens Zeiss S-tessar 300 mm f5,6

- Process lens 	Fax Rokkor 150mm F4.5

- [Sur cette page](abaque.md), des abaques permettent de corréler distance de mise au point et tirage

### Réglage de la mise au point

- Le réglage de la mise au point sur le sujet qui se trouve à l’extérieur dépend donc directement de la distance objectif/écran (tirage) et semble pouvoir être résolu avec un système mécanique de translation de l’objectif sur son axe couplé à un ou plusieurs soufflets.

- [Sur cette page](soufflet.md), une étude préparatoire à la fabrication des soufflets.

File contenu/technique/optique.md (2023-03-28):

## Principe optique

 plan d'ensemble

A : Acteur	S : Système optique	O : Opérateur		E : Écran	R : Regardeur

t : tirage	p : profondeur		h : hauteur		l : largeur	d : diamètre de l’écran

## Premiers essais

Les premiers essais ont été réalisés avec un process lens Zeiss tessar 5,6/360 chiné sur ebay.

Les process Lens étaient construits à l'origine pour des dispositifs de reproduction d’image et sont aujourd’hui utilisés par des photographes qui font du grand et du très grand format. Avec cet objectif, nous sommes arrivé à projeter une image de 60 cm de diamètre. La netteté à l'infini est obtenue en plaçant l'écran à environ 40 cm de la lentille frontale. L'image est magnifique, relativement lumineuse et incroyablement définie. Bien entendu elle est inversée. Suite à ces premiers test, nous avons identifié plusieurs problèmes à résoudre :

- [Calage des éléments optiques](calage.md) : où placer les différents éléments optiques
- [Renversement de l'image](renversement.md) : comment retourner l'image de 180° (et autres rotations)
- [Luminosité](luminosite.md) : comment obtenir l'image la plus lumineuse possible
- [Trucage optique](../technique/surimpression.md) : obtenir un système de surimpression optique type cache-contre-cache.
- [Soufflets](soufflets.md) : comment et pourquoi faire des soufflets.
- [Abaque](abaque.md) : abaque des distances de tirage pour quelques objectifs.

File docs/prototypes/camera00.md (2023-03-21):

#  Mini Camera obscura
mini_chambre_2

## Description générale
En regardant à l'intérieur de cette camera obscura, on découvre une image à l'envers d'environ 4 cm x 4 cm de ce qui est devant nous.

proto_0
## Allure
Une boite noire de forme parallélépipédique. L'image est projeté sur un dépoli à l'arrière du tube.

## Matériaux

### Parrois
- Carton-bois

mini_chambre_1
### Écran
- Toile de retroprojection (translucide/dépoli) tendue sur cadre acier

### Objectif
- objectif 24x36 monture M42 (Helios 44-2 / 2/58mm) 

### Accessoires
- L'objectif et le dépoli sont fixés sur des planchettes maintenues dans des rigoles.

## Évaluation des avantages et des inconvénients

### Avantages
- très leger
- parfait pour des tests

### Inconvénients
- image petite et inversée

## Améliorations envisagées
- placement d'un prisme de dove devant l'objectif pour retourner l'image

mini_chambre_3

## Moment envisagé pour la construction et/ou les améliorations
printemps 2023

## Détails de construction et description technique

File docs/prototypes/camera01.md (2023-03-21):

#  Les Yeux Dans Le Dos
les_yeux_dans_le_dos_4

[une vidéo de test des Yeux dans le dos](https://vimeo.com/cienokill/cameraobscura-proto01)
## Description générale
En regardant à l'intérieur de cette camera obscura, on découvre une image à l'endroit d'environ 30 cm x 30 cm de ce qui est derrière nous.

proto_01
## Allure
Une boite noire de forme complexe est fixée sur un pied de projecteur. À hauteur d'yeux on trouve un viseur en forme de lunette de protection.

## Matériaux
les_yeux_dans_le_dos_1

### Chassis
- Tube d'acier soudé (20 mm x 20 mm).

### Parrois
- Panneau de plastique alvéolaire

### Écran
- Toile de retroprojection (translucide/dépoli) tendue sur cadre acier

### Objectif
- Process lens Zeiss S-TESSAR 5,6/300

zeiss_tessar_5,6_300

### accessoires
- L'objectif fixé sur un clamp coulisse sur 2 rails
- Un soufflet en tissus fixé entre la planchette et le chassis maintient l'obscurité.

## Évaluation des avantages et des inconvénients

### Avantages
- image très claire
- à l'endroit

### Inconvénients
- image relativement petite
- axe inversé

## Améliorations envisagées
- déport de point pour faciliter le reglage de la position de l'objectif sur le rail.
- peinture du chassis
- vitre de protection et pare-soleil pour protèger les miroirs et l'objectif.

## Moment envisagé pour la construction et/ou les améliorations
printemps 2023

## Détails de construction et description technique

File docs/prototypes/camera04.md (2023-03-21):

#  Chambre Sprinter

## Description générale
Un vehicule type Sprinter Mercedes est transformé en caméra obscura en adaptant l'arrière du véhicule pour qu'il accueille un système soufflet/objectif. Un cadre sur leque est fixé l'écran de 1,80 m x 1,31 m (format 1,37) est fixé à l'intérieur du camion. 6 personnes peuvent visionner simultanémant l'image.

## Allure
Un utilitaire avec un soufflet qui dépasse à l'arrière.

proto_04

## Matériaux

### Chassis
- Sprinter Mercedes

### Écran
- Toile de retroprojection (translucide/dépoli) tendue sur cadre

### Objectif
- Process lens Wray Lustrar 16/1075mm Apo

wray_lustrar_16_1075mm_1

### Accessoires
- Pour retourner l'image, il est envisagé d'utiliser un prisme de toit d'Amici, fabriqué avec 2 miroirs à 90°.

## Évaluation des avantages et des inconvénients

### Avantages
- image dans l'axe
- ultra grand format

### Inconvénients
- à l'envers

## Améliorations envisagées

## Moment envisagé pour la construction et/ou les améliorations
printemps 2023

## Détails de construction et description technique

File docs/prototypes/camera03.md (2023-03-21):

#  Chambre grand format

## Description générale
En regardant dans le viseur situé à l'arrière de cette camera obscura, on observe une image à l'envers d'environ 100 cm x 73 cm (format 1,37) de ce qui est devant nous.

## Allure
Une boite noire de forme pyramidale couchée, fixée sur un pied de projecteur fait office de viseur de champ. Elle est prolongée par un long soufflet construit en deux partie et se termine par le support de l'objectif, lui-même fixé sur un pied. La forme evoque les chambres photographiques ultra grand format. Un pied intermédiaire limite l'affaissement du soufflet.

proto_03

## Matériaux

### Chassis
- Tube d'acier soudé (20 mm x 20 mm).

### Parrois
- Contreplaqué 5 mm

chambre_grand_format_1

### Écran
- Toile de retroprojection (translucide/dépoli) tendue sur cadre bois

### Objectif
- Process lens NIKON APO NIKKOR 9/610mm

apo_nikkor_9_610mm_2

### Accessoires
- Pour retourner l'image, il est envisagé d'utiliser un prisme de toit d'Amici, fabriqué avec 2 miroirs à 90°.

## Évaluation des avantages et des inconvénients

### Avantages
- image dans l'axe
- grand format

### Inconvénients
- encombrement
- à l'envers

## Améliorations envisagées
- fabrication et fixation soufflet carton/tissus/cuir
- peinture du chassis

## Moment envisagé pour la construction et/ou les améliorations
printemps 2023

## Détails de construction et description technique

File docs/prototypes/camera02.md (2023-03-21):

#  Chambre à Antotype
chambre_anthotype_1

## Description générale
En regardant dans le viseur situé au dessus cette camera obscura, on découvre une image à l'endroit d'environ 50 cm x 50 cm de ce qui est devant nous. L'écran est amovible et peut être remplacé par une plaque sur laquelle on aura disposé un papier photo-sensible type antotype.

proto_02
## Allure
Une boite noire de forme complexe est fixée sur un pied de projecteur. La forme evoque les chambres moyen-format type rolleiflex. Sur le dessus, on trouve un viseur en forme de lunette de protection. À l'avant, une vitre protège le miroirs et l'objectif.

## Matériaux

### Chassis
- Tube d'acier soudé (20 mm x 20 mm).

### Parrois
- Panneau de plastique alvéolaire et contreplaqué 5 mm

### Écran
- Toile de retroprojection (translucide/dépoli) tendue sur cadre acier

### Objectif
- Process lens APO RONAR RODENSTOCK 9/360 mm

### Accessoires
- L'objectif fixé sur un clamp coulisse sur un rail Igus
- Un soufflet provisoire en tissus fixé entre la planchette et le chassis maintient l'obscurité dans la boite.

## Évaluation des avantages et des inconvénients

### Avantages
- image dans l'axe
- à l'endroit

### Inconvénients
- visée par le dessus
- peu clair

## Améliorations envisagées
- fabrication soufflet carton/tissus/cuir
- déport de point pour faciliter le reglage de la position de l'objectif sur le rail.
- peinture du chassis
- vitre de protection et pare-soleil
- fixation des lunettes
- achat objectif plus lumineux

## Moment envisagé pour la construction et/ou les améliorations
printemps 2023

## Détails de construction et description technique

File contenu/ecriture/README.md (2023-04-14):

# Écriture

*En travaux*

C'est un court metrage de 20 minutes sous forme de notes ou de fragments qui s'enchaînent.

- [Vrac](vrac.md), Des idées en vrac.
- [Narratologie](narratologie.md), Comment construire le film.
- [Scenario 1](scenar1.md), Le scénario qu'on avait mis dans le dossier de création.
- [Sequences](sequences.md), Des idées de séquences.

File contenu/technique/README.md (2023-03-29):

# Technique

*En travaux*

Voici la liste des défis techniques liés au spectacle *Camera Obscura*. Dès qu'on a du contenu à propos d'un de ces points, on crée un fichier et on met le lien du fichier dans la liste.

- [Introduction](introtechnique.md) : principes généraux qui guident notre travail

## Optique
- [Principes optiques](optique.md) : généralités sur la caméra obscura
- [Calage des éléments optiques](calage.md) : où placer les différents éléments optiques
- [Renversement de l'image](renversement.md) : comment retourner l'image de 180° (et autres rotations)
- [Luminosité](luminosite.md) : comment obtenir l'image la plus lumineuse possible
- [Trucage optique](../technique/surimpression.md) : incrustation et surimpression
- [Soufflets](soufflets.md) : comment et pourquoi faire des soufflets.
- [Abaque](abaque.md) : abaque des distances de tirage pour quelques objectifs.

## Audio
- [diffusion du son dans la remorque](son.md) : comment donner l'illusion du son cinéma

## Accueil public
- [Isolation et climatisation](isolation.md), faire du frais dans la remorque
- Vendre des pop-corns cuits au four solaire.

## Divers
- [Fournisseurs](fournisseurs.md), liste de fournisseurs.
- [Vrac](vrac.md), idées à creuser.

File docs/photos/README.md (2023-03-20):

Dossier rassemblant toutes les photos liées à la création

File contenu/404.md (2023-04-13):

---
permalink: /404.html
---

## Erreur 404

**Cette page n'existe plus, pas ou pas encore.**

ovni

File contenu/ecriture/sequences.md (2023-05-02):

---
type: scenario
---

## Séquence : Camionnette rouge

*2D : Une camionnette roule sur une route bordée d'arbres*

**VOIX OFF**

Un de ces jours où je devais me rendre à un certain endroit j'ai été pris en stop par une camionnette rouge.

On n'a presque pas parlé pendant une heure, peut-être même que j'ai un peu dormi. Et puis soudain la camionnette m'a dit :

*Conducteur au volant d'une voiture, parle à la caméra (doublé par la voix off)*

**VOIX OFF**

"Ce qui est le plus important, c'est de travailler son imagination, Pour ça il y a plein d'exercices que l'on peut faire au quotidien. Par exemple, s'imaginer ce qu'il y a derrière un mur, s'imaginer que telle chose que l'on regarde est d'une autre couleur.

Par exemple quand je suis assis à une table, j'imagine d'autres objets posés dessus. Il faut commencer par des objets familiers que l'on connait bien, puis on peut ajouter des objets inventés, Des objets animés, sonores, des objets lumineux qui éclairent d'autres objets.

On peut aller très loin comme ça. En fait tout est possible, le tout c'est de pratiquer tous les jours."

## Séquence : L'hiver.

*Gros plan personne toute en sueur*

**VOIX OFF**

Parfois en ces temps-ci, la chaleur de l'été est insuportable

*2D : schéma explicatif à la "C'est Pas Sorcier" de l'eau qui bout dans le corps*

**VOIX OFF**

Tout fond autour de moi et à l'intérieur de moi. L'eau de mon corps se met à bouillir, la vapeur ainsi produite envahit mon cerveau et tout devient brumeux. Le sol fond, mes chaussures fondent, elles collent au sol, je ne peux plus me déplacer, je deviens immobile, je perds ma mobilité, je deviens immeuble.

*Gros plan personne emmitoufflée dans une écharpe, de la buée sort de sa bouche, de la neige tombe.*

**VOIX OFF**

La technique consiste alors à s'imaginer qu'il fait froid, froid comme le coeur de l'hiver dans une région froide, vraiment froide, une région froide comme on n'en fait plus. Je resterais comme ça quelques minutes puis je retournerais à l'été juste avant de tomber malade.

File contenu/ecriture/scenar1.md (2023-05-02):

---
type: scenario
---

*Plan large d'une place animée d'un centre ville. Des enfants courent, des passants passent, d'autres sont assis sur des bancs ou sur des marches.*

**VOIX OFF**

L’homme que vous voyez là-bas au milieu de l’écran qui fume une cigarette assis à côté du type avec une chemise rose, c’est moi. J’ai eu une matinée difficile, pas mal de problèmes au boulot et je viens volontairement d'ignorer un appel téléphonique de mon chef. C’est la première fois que je fais ça...

Non pardon, c’est une blague en vrai je suis le type avec la chemise rose.

*Le type avec la chemise rose fait un signe de la main en direction de l'objectif.*

**VOIX OFF**

Je m’ennuie et comme souvent quand je m’ennuie je choisis un passant au hasard et je fais semblant d’être lui. J'imagine sa vie, je me raconte son histoire. Ça fait une demi-heure que je joue à ça et je commence à en avoir marre, j’aimerais bien trouver une idée plus amusante...

C'est toujours pareil quand je cherche une idée, plus je réfléchis, plus je me concentre et plus c'est le vide dans ma tête. J'ai pas l'impression que ce soit pareil pour tout le monde...

Oh ! vous avez vu ? La dame qui vient de passer on dirait qu’elle a plein d’idées très drôles, ça se voit à comment elle marche.

*L'homme se lève.*

**VOIX OFF**

Il parait que la pensée fonctionne mieux en marchant. Normalement le cerveau s'irrigue mieux quand le corps est en mouvement. on va voir si c'est vrai.

*L'homme fait les 100 pas...*

*L'homme s'arrête brusquement.*

**VOIX OFF**

J’ai une idée ! On va se marrer. Je vais faire semblant que je vois une soucoupe volante qui traverse le ciel et les gens vont halluciner.

*Une boule de feu en forme de soucoupe volante traverse le ciel. L'homme la montre du doigt en criant dans l'indifférence générale.*

**VOIX OFF**

Je crois que j'ai un genre de syndrome de Capgras. Vous avez entendu parler du syndrome de Capgras ? C'est horrible. C'est quand on pense qu'on est entouré d'imposteurs qui se font passer pour des proches. 

*L'homme regarde la foule autour de lui.*

**VOIX OFF**

Comment expliquer autrement que personne n'ait réagi en voyant la soucoupe volante ? La seule explication possible, c'est que tous les autres sont de mèche pour me faire croire que les extraterrestres n'existent pas.

*L'homme se retourne. On le voit de dos.*

**VOIX OFF**

Néanmoins j’ai de très bonnes raisons de penser que les extraterrestres existent...

*Gros plan. L'homme se retourne face à nous. C'est un alien.*

**VOIX OFF**

Je rigole.

*Il enlève son masque.*

**VOIX OFF**

C'est n'importe quoi…

*L'homme repart dans sa déambulation*

**VOIX OFF**

C'était pas une super idée. Je vais essayer de trouver mieux.

*L'homme fait les 100 pas.*

*Petit à petit il modifie sa démarche jusqu’à ce que les 100 pas ressemblent à une danse.*

**VOIX OFF**

J’ai une idée, je vais faire semblant qu’il y a de la musique. On va voir, si je danse rigoureusement en rythme avec une musique imaginaire, peut-être les gens auront l’impression d’entendre la musique...

*Il invite une dame à danser. La dame accepte l'invitation et le couple entame une valse au milieu de la place.*

**VOIX OFF**

La dernière fois que j'ai dansé la valse avec une inconnue c'était place Rouge à Moscou.

*De la neige tombe sur les danseurs qui sont maintenant sur la place Rouge.*

**VOIX OFF**

Il y avait un violoniste qui jouait. Quand il s’est arrêté on a tous les deux fait semblant d’être en retard ou d’avoir quelque chose d’important à faire et on ne s’est jamais revu.

*Les deux personnes se séparent et partent dans des directions opposées. La dame sort du champ, l'homme revient au centre de l'image et cherche la danseuse du regard.*

**VOIX OFF**

Ho mince, j'avais un petit cadeau pour elle et j'ai oublié de lui donner. Je sais même pas comment elle s'appelle... C'est trop bête.

*Un peu désemparé, l'homme scrute les visages autour de lui.*

**VOIX OFF**

Bon, je vais l'offrir au gars qui a des problèmes avec son chef.

*Il s'approche de l'homme à la cigarette et lui tend un cadeau fictif, assez gros, que l'autre accepte volontiers. Les deux hommes se mettent face à face sur la place à environ 15 mètres l'un de l'autre. L'homme de droite est au service. Il lance une balle fictive en l'air qu'il frappe avec la raquette fictive que l'autre vient de lui offrir. Un match de tennis très serré s'engage au milieu des passants.*

**BRUITAGE**

Poc, poc, poc, poc. Bruits d'applaudissements. 15/0. Poc, poc, poc, poc, poc, poc, Bruits d'applaudissements. 30/0. etc...

*Fin du match, les deux hommes se serrent la main très sportivement.*

**VOIX OFF**

Le gars était trop fort pour moi. J'suis claqué. Je crois que je vais m'allonger un peu.

*L'homme cherche un endroit adapté pour faire une sieste, s'installe et soupire de bien-être.*

**VOIX OFF**

Hooaaaa. On est bien ici. Les gens sont beaux. C'est un bon endroit pour faire sa maison. Pas une grosse maison, juste une petite cabane...

*à suivre...*

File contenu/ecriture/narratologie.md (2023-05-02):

# Narratologie

Deux options pour construire le film. Dans les deux cas on a enchaîné des fragments, des notes. On change de cadre spatiotemporel et de ton comme de chemise. Mais la question est de savoir comment ces fragments sont reliés.

## schéma narratif classique

Raconter une histoire en suivant un schéma narratif classique situation initiale, complication, résolution.

1. De manière fantastique des personnes sont capables de modifier la réalité à l'aide de leur imagination. On suit les aventures de ces personnes. -> C'est fun
2. Bien qu'extrêmement puissant ce pouvoir de l'imagination, ça reste seulement dans leur tête. Ils ne peuvent pas véritablement modifier la réalité.
3. Un événement grave se produit ou alors on se heurte à une réalité et à l'impuissance de l'imagination face à cette réalité. -> C'est triste.
4. Finalement au fond du trou on découvre que l'imagination peut vraiment tout faire y compris changer le monde autour et on règle le problème de base. -> C'est joyeux

## Fragments décousus

On a un thème par exemple le pouvoir de l'imagination et on enchaîne les saynètes qui n'ont pas de rapport entre elles à part dans le style et vaguement dans le thème. L'ordre des séquences n'a pas vraiment d'importance. On comprendrait aussi bien en ratant le début ou en partant avant la fin. Plus comme un spectacle de cirque ou un recueil de Danhil Harms.

## Le pour et le contre de ces deux options 

Pour le schéma narratif classique :

- Reprendre les codes du cinéma est une des idées de base du projet. Ça peut s'appliquer aussi à la structure narrative.
- Plus de chances de transmettre des émotions (pleurer devant un film c'est pour moi part entière de l'expérience du cinéma).

Pour les fragments décousus :

- Plus dans la lignée de ce que l'on sait faire et de ce qu'on a fait dans les autres spectacles de la Cie.
- Peut-être plus adapté au format court mettrage (20 min est-ce suffisant pour développer une histoire dans un schema narratif classique?)
- Plus original

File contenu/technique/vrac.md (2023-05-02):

- lyre retournement
- hublot iris
- est-ce qu'on peut graver des disques pour gramophone

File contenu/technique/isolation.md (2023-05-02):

## Gestion de la chaleur à l'intérieur de la remorque

Camera Obscura est un spectacle de rue, diffusé en été, et nécessitant une bonne luminosité extérieure. La remorque va donc être placée en plein soleil et le problème du confort thermique des spectateurs est un point essentiel à régler pour la réussite de cette création. Nous cherchons donc des solutions techniques dans les domaines suivants :

### Traitement de surface de la remorque
- Application d'un peinture ou pose d'un revètement antichaleur sur la remorque pour limiter le rayonnement solaire (peinture bi-composant spécifique, matiériau collé type couverture de survie ?).

### Isolation thermique
- Utilisation d’un isolant efficace, de faible épaisseur et de faible poids. Les contraintes de dimension (largeur) et de jauge (24 spectateurs) nous imposent une épaisseur d’isolant très réduite. Nous imaginons que de tels matériaux sont utilisés en aéronautique et programmes spatiaux. Peut-être pouvons-nous récupérer des lots obsolètes ou périmés d'isolants ? Épaisseur max envisagée : 100 mm.

### Renouvellement de l’air
- Mise en place d'un système de renouvellement de l’air à l’intérieur de la remorque. Nous imaginons un système d'extraction d'air composé de 2 gaines équipées de bouches d'aération placées sur les côtés en haut sur tout le long de la remorque et qui débouchent sur l'extérieur.
L'arrivée d'air se ferait par le sol à travers des bouches d'aération individuelles sous chaque siège.
Cette implantation permettrait une convection naturelle. Mais peut-être faut-il imaginer un ventilation mécanique pour forcer l'extraction et accélérer le renouvellement de l'air (manivelle ou pédalier et volant d’inertie ?).

### Raffraichissement de l’air

- Installation de systèmes de rafraichissement d'air sur le trajet du flux. En s'inspirant des climatisations pour chapiteau, ou un flux d'air traverse un ballot de paille humide (RAF : rafraîchisseur d'air évaporatif) imaginer des caissons de paille régulièrement humidifiés sur le chemin de l'air. Le plus simple semble être des caissons placés sous les sièges des spectateurs.

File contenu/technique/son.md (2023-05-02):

## Le son au cinéma

Par rapport au projet de créer l’illusion d’un film, il nous semble important de recréer l’ambiance sonore perçue par le spectateur dans une projection moderne :
    composition de la bande son (son direct, doublage, bruitage, FX, sound-design, ambiance et musique)
    effet de spatialisation sonore,
    effet d’infra-basses

### Spacialisation

- Nous aimerions étudier la faisabilité d’un système de tuyaux et de pavillons pouvant acheminer et spacialiser des sources sonores produites acoustiquement dans la remorque : voix humaine, instrument, gramophone, etc.

### Effet d’infra-basses

- Pour reproduire les sensations physiques éprouvées dans une salle de cinéma, nous imaginons pouvoir faire « vibrer » les sièges à la façon d’un subwoofer. À étudier le faisabilité d’une vibration produite par frottement d’une came dentelée contre une butée, transmise de façon solidienne aux sièges des spectateurs, eux-mêmes fixés sur silent-blocs.

### Isolation sonore

- Il est important de soigner l’isolation sonore de la remorque, pour diminuer le bruit venant de l’extérieur. L’immersion des spectateurs nécessite qu'ils soient un minimum protégés du bruit extérieur, le spectacle étant surtout joué dans des environnements urbains (voitures, passants, etc.).
Ce problème peut être traité conjointement aux soucis d’isolation thermique évoqués dans la page [isolation et climatisation](isolation.md)

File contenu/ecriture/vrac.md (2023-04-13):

# Vrac à idées

- écriture fragmentée : beaucoup de tableaux, des fragments, matières pour improviser en fonction du lieu
- pouvoir de l'imagination (le décor) : une montagne a poussé rue Jean-Jaures...
- pouvoir de la suggestion (température ambiante) : il fait ultra froid dans le film, de la neige
- écriture à la Daniil Harms : une évocation, un texte, une image et on passe à autre chose
- avec ou sans texte. On peut le jouer à l'étranger ? Du doublage ?
- alterner animation et prises de vues réelles
- trucage : des marionnettes répliques réalistes des comédiens
- travelling en voiture, image à l'envers
- sur quoi est posée la personne qui porte la terre ? une image de poirier à l'envers
- escalader le monde à 90 °
- trucage : être dans l'eau, mate painting, cache contre cache (un nouvel élément de décor dans le décor du quotidien)
- des passages 100 % dessin et animation

# Vrac à élements de langage

- Unplugged
- postcinéma
- Lowtech
- metamodernisme ?

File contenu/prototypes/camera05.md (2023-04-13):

#  Chambre Remorque

## Description générale
Une remorque est transformée en cinéma itinérant en adaptant l'arrière du véhicule pour qu'il accueille un système soufflet/objectif. Un cadre sur lequel est fixé l'écran de 1,80 m x 1,31 m (format 1,37) est installé à l'intérieur de la remorque. 20 personnes assisent sur un gradinage peuvent assister simultanémant à la projection.

Dessin de la remorque
*Vue de la remorque, un&middot;e opérateurice sur le toit pour les effets spéciaux et les marionnettes ; un&middot;e derrière l'écran pour le système optique principal et le son ; le public est réparti sur 5 rangées de sièges*

## Allure
Une remorque avec un soufflet qui dépasse à l'arrière.

proto_05
## Matériaux

### Chassis
- Remorque BW TINY HOUSE CH 600 et charpente alu.

### Écran
- Toile de rétroprojection (translucide/dépoli) tendue sur cadre

### Objectif
- à définir

### Accessoires
- Pour retourner l'image, il est envisagé d'utiliser un prisme en toit d'Amici, fabriqué avec 2 miroirs à 90°.

## Évaluation des avantages et des inconvénients

### Avantages
- image dans l'axe
- ultra grand format
- très confortable

### Inconvénients

## Améliorations envisagées
- trappe entre salle et cabine (sous l'écran)
- hublots avec fermeture (iris ?)
- trappe entre cabine et extérieur avec sas.
- rideau sur l'écran ?
- système de ventilation mécanique
- système de refroidissement paille/eau
- porte PMR 90 cm
- retourner la flèche

## Moment envisagé pour la construction et/ou les améliorations
automne 2023

## Détails de construction et description technique

dimension hors-tout caisse + chassis : 7473 x 2450 x 3048

dimension hors-tout caisse : 6000 x 2450 x 24000

dimension utile intérieur : 5800 x 2250 x 2300

épaisseur isolation plafond ou mur : 100

épaisseur isolation sol : 120

entraxe siège mini : 500

largeur traversée mini : 350

assise mini : 500

hauteur dossier : 700

largeur accoudoir : 60

[plan chassis remorque](../plans/doc_bw_tiny_house_ch600.pdf)

plan chassis remorque

plan cotes remorque

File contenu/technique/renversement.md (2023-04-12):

# Renversement de l’image

En utilisant un objectif ou une lentille simple, sur l’image projetée le haut et le bas sont inversés. Il faut réussir à retourner l’image pour rétablir son orientation haut-bas. 
L’idéal serait d’éviter aussi une inversion droite-gauche mais ce n’est pas prioritaire.

## Tour d'horizon des solutions pour régler le problème du renversement

prisme en toit
*Un prisme en toit d'Amici réalisé avec deux miroirs*

Plusieurs pistes envisagées :

### Retourner les spectateurs

Solution éliminée car c'est trop inconfortable voire dangereux d'être la tête en bas pendant 20 minutes.

### Équiper les spectateurs de lunettes retournant l'image

Cette solution, séduisante sur le papier, comporte quelques défauts : qualité médiocre, champ limité, gestion des lunettes pendant les séances, prix...

### Retourner comédiens et décors

Artistiquement très intéressante, cette option sera utilisée pour certaines séquences : ombres et animation, marionnettes à l'envers, comédiens suspendus.

### Retourner l'image

- Nous n’avons pas trouvé de solution fiable pour régler ce problème en dehors de l’utilisation de prismes géants de Dove, de Poro-Abbe ou en toit d'Amici ou avec des miroirs de grande taille.
- Nous nous demandons si une solution sans prisme ou miroir est possible ? Si nous sommes contraints d’utiliser des prismes de grande taille, comment et où se procurer de tels objets.
- Si nous devons utiliser des grands miroirs, comment limiter les défauts optiques observés lors des essais : perte de luminosité, double image, trait central dans le prisme en toit d'Amici... (miroir extra clair anti reflet, miroir first face..?)

## Les solutions à miroirs

### Simulation

Voici une [simulation des solutions envisagées avec des miroirs](/contenu/simulation/mirrors/). Utilisez le clic gauche et la molette pour naviguer dans la scène. Utilisez la petite fenêtre en haut à droite pour sélectionner une scène et régler l'angle du champ de vision.

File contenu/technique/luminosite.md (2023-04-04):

## Luminosité de l’image

Nous souhaitons que l’image soit la plus lumineuse possible. Solutions envisagées :

### Choix des périodes de jeu

Pour maximiser la luminosité de l’image la première chose à faire est de maximiser la luminosité du sujet filmé. Notre seule source de lumière étant le soleil, il sera necessaire de limiter les moments de jeu :

- plage horaire (e.g. de 11h à 16h)
- période de l’année (e.g. mai-septembre)
- conditions météo (ciel dégagé).

Ces conditions sont contraignantes, nous souhaitons les assouplir au maximum en travaillant sur les deux points suivants.

### Luminosité du système optique

- Pour obtenir un maximum de luminosité, il est nécessiaire d’utiliser des très grandes lentilles.

- Il nous a semblé important d’utiliser des objectifs achromatiques, asphériques afin de limiter au maximum les aberrations et obtenir une bonne qualité d’image qui évoque les impressions ressenties dans une salle de cinéma. Nous avons donc recherché ce type d'objectifs, mais avec de très grands diamètres pour gagner en luminosité. Nous avons trouvé des optiques qui répondent partiellement à ces critères : les process lens. Mais, même sur les plus gros modèles, les lentilles ne dépassent jamais 100 mm de diamètre.

- Nous nous posons la question de savoir si des lentilles simples, de très grand diametre (200 mm ou plus) apporteraient un plus en terme de luminosité, sans trop sacrifier la qualité de l'image. Nous serions intéressés pour récupérer des éléments optiques issus de matériel obsolète (Matériel de laboratoire ?, vieux télescope géant ?, lunette astronomique ? etc.) pour tester ce type de solutions. focale recherchée (2000 mm)

### Obscurité de la salle

La salle où le public est installé doit être la plus obscure possible. Cela ne changera pas la luminosité réelle de l’image mais la luminosité ressentie.
 Cela implique :

- Une parfaite étanchéité lumineuse de la salle.
- Les murs de la salle faits dans des materiaux sombres, reflétant très peu la lumière, afin que la lumière de l’écran “bave” le moins possible sur les murs.

### Rendement de l'écran

L'image est projetée en rétroprojecion (par l'arriére de l'écran). Differentes qualités de toiles de rétroprojection existent. Après plusieurs essais nous avons selectionné le Teviloj Retro Translucide.

test toiles retroproj

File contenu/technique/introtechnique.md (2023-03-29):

## Cahier des charges général

Voici quelques indications générales sur les parti-pris et les choix techniques dans cette création.

### Reproduire les codes du cinéma

À la base de la plupart des questions évoquées ici, il y a la volonté de reproduire un maximum de codes du cinéma pour faire vivre au public l’expérience d’une projection.

À l’image ça ouvre les questions de montage, de l’utilisation de différents axes de prises de vue, de différentes échelles de plan, et l’enchainement de ces différentes valeurs avec des transitions (cut, fondu, etc.). Mais aussi les questions de trucages et d’effets visuels.

Au son ça ouvre, entre autres, les questions de musique, de voix off et de bruitage et de diffusion multicanal.

### Mobilité du dispositif

Le dispositif doit être mobile et sera construit sur un châssis de remorque. Cela impose des contraintes de taille et de poids.

### Le parti pris énergétique

Une des idées fondatrices du spectacle est de s’imposer la contrainte de n’utiliser aucun apport d’énergie autre que la lumière du soleil et la force humaine. Cette contrainte est au coeur même du projet et permettra au spectacle d’être diffusé même dans des endroits sans accès à l’electricité : au milieu du désert, sur une plage, etc.

En outre, l’utilisation d’énergie électrique de source photovoltaïque ou mécanique (force humaine ou éolien) ne s’oppose pas directement à cette contrainte mais nous souhaitons si possible nous en passer pour ce spectacle.

### Low-tech et récupération

Notre projet s’inscrit dans la continuité du travail de la Cie, où nous cherchons à utiliser des dispositifs simples et ancestraux sans renoncer aux imaginaires et aux formes que le progrès et la modernité à engendrés.

Aussi, il nous semble important de privilégier au maximum la récupération de matériaux et d’objets obsolètes pour leur redonner vie au travers d’une démarche artistique.

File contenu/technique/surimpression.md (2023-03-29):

## Incrustation et surimpression

Parmi les effets visuels et trucages que nous envisageons d’explorer, il y a l’idée de développer des dispositifs d'incrustation ou de surimpression optique.
L’idée est de créer des systèmes optiques qui permettraient d'incruster un élément visuel venant soutenir la narration sur une petite partie de l’image.

### Cache contre cache (incrustation)
Sur le toit de la remorque, des transparents ou des jeux d'ombres éclairés par le soleil, transitent par un objectif et un miroir pour apparaitre sur l'écran. 
Un système de cache et de contre cache permet d'éviter les surimpressions.

### Projection de diapo (surimpression)

Nous imaginons un système de lentilles placé à l’extérieur qui concentre la lumière du soleil.
Une fibre optique de gros diamètre qui transporte cette source vers un dispositif type mini-projecteur de diapo pouvant être manipulé à la main à l’intérieur de la remorque par l'opérateur dissimulé derrière l'écran.
Dans ce cas l'image projetée se rajoute à celle qui apparaît sur l'écran pour créer un effet de surimpression type fantôme.

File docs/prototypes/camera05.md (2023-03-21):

#  Chambre Remorque

## Description générale
Une remorque est transformé en cinéma itinérant en adaptant l'arrière du véhicule pour qu'il accueille un système soufflet/objectif. Un cadre sur leque est fixé l'écran de 1,80 m x 1,31 m (format 1,37) est fixé à l'intérieur de la remorque. 20 personnes assisent sur un gradinage peuvent visionner simultanémant l'image.

Dessin de la remorque
*Vue de la remorque, un&middot;e opérateurice sur le toit pour les effets spéciaux et les marionettes ; un&middot;e derrière l'écran pour le système optique principal et le son ; le public est réparti sur 5 rangées de sièges*

## Allure
Une remorque avec un soufflet qui dépasse à l'arrière.

proto_05
## Matériaux

### Chassis
- Remorque BW TINY HOUSE CH 600 et charpente alu.

### Écran
- Toile de retroprojection (translucide/dépoli) tendue sur cadre

### Objectif
- à définir

### Accessoires
- Pour retourner l'image, il est envisagé d'utiliser un prisme de toit d'Amici, fabriqué avec 2 miroirs à 90°.

## Évaluation des avantages et des inconvénients

### Avantages
- image dans l'axe
- ultra grand format
- très confortable

### Inconvénients

## Améliorations envisagées

## Moment envisagé pour la construction et/ou les améliorations
automne 2023

## Détails de construction et description technique

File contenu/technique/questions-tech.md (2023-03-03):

# Camera obscura - Questionnements et besoins techniques

Camera Obscura est un spectacle de rue qui plonge le spectateur dans un dispositif cinématographique ancestral, sans pellicule, ni vidéo, ni électricité, et qui n'utilise comme énergie que celle du soleil et des comédiens. Le public s'installe dans un lieu fermé, une chambre noire (camion ou remorque), et assiste à la projection d'un film dont les images sont des captations du monde extérieur qui transitent par un dispositif optique fait d'objectifs, de prismes et de miroirs. Les sons et la musique sont produits et interprétés en direct grâce à un ensemble d'instruments acoustiques et mécaniques : gramophones, automates sonores, cymbalum, tuyaux et pavillons acoustiques.

En résumé, l’enjeu principal de cette création est de créer l’illusion de la projection d’un film sans se brancher sur le courant. Vous trouverez plus de contenus et d'intentions artistiques dans le dossier de création en pièce jointe.

Nous avons identifié 3 domaines pour lesquels nous recherchons des partenariats (compétences, matériaux et conseils de mise en œuvre) :

- L’optique (voir 1. Image)
- L’isolation thermique (voir 2. Chaleur)
- L’accoustique (voir 3. Son)

## 0. Cahier des charges général

Voici quelques indications générales sur les partis pris et les choix technique qui dans cette création.

### 0.1. Reproduire les codes du cinéma

À la base de la plus-part des questions évoquées ici, il y a la volonté de reproduire un maximum de codes du cinéma pour faire vivre au public l’experience d’une projection.

À l’image ça ouvre les questions de montage de l’utilisation de differents axes de prises de vue, de differentes échelles de plan, et l’enchainement de ces differentes valeurs avec des transitions (cut, fondu, etc.). Mais sussi les questions de trucages et d’effets visuels.

Au son ça ouvre, entre autre, les questions de musique, de voix off et de bruitage.

### 0.2. Mobilité du dispositif

Le dispositiaf doit être mobile et sera construit sur un chassis de remorque. Cela impose des contraintes de taille et de poid.

### 0.3. Le parti pris energetique

Une des idées fondamentale du spectacle est de s’imposer la contrainte de n’utiliser aucun apport d’énergie autre que la lumière du soleil est la force humaine. Cette contrainte est au coeur même du projet et permettra d’être diffusé même dans des endroits sans accès à l’electricité : au milieu du désert, sur une plage, etc.

En outre, l’utilisation d’énergie electrique de source photovoltaïque ou mécanique (force humaine) ne s’oppose pas directement à cette contrainte mais nous souhaitons si possible nous en passer pour ce spectacle.

### 0.4 Low-tech et récupération

Notre projet s’inscrit dans la continuité du travail de la Cie, où nous cherchons à utiliser des dispositifs simples et ancestraux sans renoncer aux imaginaires et aux formes que le progrès et la modernité à engendré.

Aussi, il nous semble important de privilégier au maximum la récupération de matériaux et d’objets obsolètes pour leur redonner vie au travers d’une démarche artistique.

### 0.5 Schéma simplifié du dispositif

 plan d'ensemble

A : Acteur	S : Système optique	O : Opérateur		E : Écran	R : Regardeur

t : tirage	p : profondeur		h : hauteur		l : largeur	d : diamètre de l’écran

## 1. Image

Les premiers essais ont été réalisés avec un process lens Zeiss tessar 5,6/300 chiné sur ebay.

Les process Lens étaient construits à l'origine pour des dispositifs de reproduction d’image et sont aujourd’hui utilisés par des photographes qui font du grand et du très grand format. Avec cet objectif on arrive à projeter une image de 60 cm de diamètre. La netteté est obtenue en plaçant l'écran à environ 30 cm de l'objectif. L'image est magnifique, relativement lumineuse et incroyablement définie. Bien entendu elle est inversée. Suite à ces premiers test, nous avons identifié plusieurs problèmes à résoudre :

- Obtenir un maximum de luminosité même par temps couvert

- Le problème du retournement de l’image

- Le calage de la distance entre l’objectif et l’écran et la taille de l'image

- La possibilité de régler la mise au point sur le sujet qui se trouve à l’extérieur

- La conception d’un système de surimpression optique

### 1.1. Luminosité de l’image

Nous souhaitons que l’image soit la plus lumineuse possible.

Le besoin d’avoir le maximum de luminosité est essentiel pour que l’experience soit réussie.

Nous avons identifié trois moyens d’actions:

- Choix des périodes de jeu.

- Luminosité du système optique.

- Obscurité de la salle.

- Rendement de l'écran.

#### 1.1.1.  Choix des périodes de jeu

Pour maximiser la luminosité de l’image la première chose à faire est de maximiser la luminosité du sujet filmé. Notre seule source de lumière étant le soleil, il sera necessaire de limiter les moments de jeu :

- plage horaire (e.g. de 11h à 16h)

- période de l’année (e.g. mai-septembre)

- conditions météo (ciel dégagé).

Ces conditions sont contraignante, nous souhaitons les assouplir au maximum en travaillant sur les deux points suivant.

#### 1.1.2.  Luminosité du système optique

Pour obtenir un maximum de luminosité, il est nécessiaire d’utiliser des très grandes lentilles.

Il semble essentiel d’utiliser des lentilles achromatiques, asphériques afin de limiter au maximum les aberrations et obtenir une bonne qualité d’image. Nous recherchons donc ce type de lentille, mais avec de très grands diamètres pour gagner en luminosité. Nous serions intéressés pour récupérer des éléments optiques issus de matériel obsolète (Matériel de laboratoire ?, vieux télescope géant ?, lunette astronomique ? etc.) et trouver des solutions pour les adapter à notre usage.

Il faut également être attentif aux pertes de luminosité engendrées par les miroirs ou prismes uttilisée pour retourner l’image (voir point 1.2.) et tenter de minimiser ces pertes (chercher les meilleures qualité de miroir / minimiser le nombre de miroirs)

#### 1.1.3. Obscurité de la salle

Cela ne changera pas la luminosité réelle de l’image mais la luminosité ressentie.

La salle où le public est installée doit être la plus obscure possible. Cela implique :

- Une parfaite étanchaité lumineuse de la salle.
- Les murs de la salle faits dans des materiaux sombres, reflétants très peu la lumière, afin que la lumière de l’écran “bave” le moins possible sur les murs.

#### 1.1.4. Rendement de l'écran

L'image est projettée en retroprojecion (par l'arriére de l'écran). Differentes qualités de toiles de retroprojection existent.

Après plusieurs essais nous avons selectionné le Teviloj Retro Translucide.

test toiles retroproj

### 1.2. Retournement de l’image

Sur l’image projettée le haut et le bas sont inversés, Il faut réussir à retourner l’image pour rétablir son orientation haut-bas. L’idéal serait d’éviter aussi une inversion droite-gauche mais ce n’est pas prioritaire.

Nous n’avons pas trouvé de de solution théorique fiable pour régler ce problème en dehors de l’utilisation de prismes géants de dove ou d’Abbe-Porro ou avec des miroirs de grande taille.

Nous nous demandons si une solution sans prisme ou miroir est possible ? Si nous sommes contraint d’utiliser des prismes ou des miroirs, comment se procurer de tels objets (taille très grande), et comment limiter la perte de luminosité due à leur utilisation.

### 1.3. Taille de l’image et distance de tirage

Nous aurions aimé une distance entre objectif et écran de au minimum 1 m pour des raisons pratiques d’implantation de l’écran dans la remorque et une taille d’image de 2 m de diamètre.

Une difficulté vient du fait que nous aimerions utiliser plusieurs objectifs avec des focales différentes, voire des renvois d’angle, et alterner leur usage avec un système de caches manuels afin de reproduire l’illusion d’un montage type cinéma où plusieurs plans différents s’enchaînent. Il faudrait donc trouver le moyen d’homogénéiser le tirage de tous ces objectifs et la taille des images obtenues.

### 1.4. Réglage de la mise au point

La possibilité de régler la mise au point sur le sujet qui se trouve à l’extérieur semble pouvoir être résoleu avec un système mécanique de translation de l’objectif sur son axe.

À trouver la bonne solution : simple, fiable et pratique

### 1.5. Surrimpression de diapo

Parmis les effets visuels et trucages que nous envisageons d’explorer, il y a l’idée d’un dispositif de surrimpression optique.

L’idée est de créer un système optique qui permettrait d'incruster un élément visuel venant soutenir la narration sur une petite partie de l’image. Nous imaginons un système de lentille placée à l’extérieur qui concentre la lumière du soleil, une fibre optique de gros diamètre qui transporte cette source vers un dispositif tyre mini-projecteur de diapo pouvant être manipulé à la main à l’intérieur de la remorque.

## 2. Chaleur

Camera Obscura est un spectacle de rue, diffusé en été, et nécessitant une bonne luminosité extérieure. La remorque va donc être placée en plein soleil et le problème du confort thermique des spectateurs est un point essentiel à régler pour la réussite cette création. Nous cherchons donc des solutions techniques qui répondent aux critères suivants :

- utilisation d’un isolant efficace, de faible épaisseur et de faible poids
- système de renouvellement de l’air à l’intérieur de la remorque
- rafraichissement de l’air

### 2.1. Isolation thermique

Nous souhaiton trouver un isolant efficace, de faible épaisseur et de faible poids

Les contraintes de dimensions (largeur) et de jauge (24 spectateurs) nous impose une épaisseur d’isolant très réduite. Nous imaginons que de tels matériaux sont utilisés en aéronautique et programmes spatiaux. Peut-être pouvons nous récupérer des lots obsolètes ou périmés d'isolants ?

En parallèles, nous envisageons un système démontable de toile tendue au dessus de la salle afin qu’elle ne soit pas directement exposée au soleil.

### 2.2. Renouvellement de l’air

Nous imaginons un système de gaines dont l’implantation permettrait une convection naturelle. Mais peut-être faut-il imaginer un ventilation mécanique et trouver une force pour l’animer (manivelle ou pédalier et volant d’inertie ?)

### 2.3. Raffraichissement de l’air

La mise en place d’un système de rafraichissement de l’air sans electricité semble compliqué à résoudre… Peut-être en utilisant un liquide sur la route du flux de ventilation ?

## 3. Son

Par rapport au projet de créer l’illusion d’un film, il nous semble important de recréer l’ambiance sonore perçue par le spectateur dans une projection moderne :

- effet de spatialisation sonore
- effet d’infra-basses

La question se pose aussi de l’isolation sonore. Pour diminuer le bruit venant de l’exterieur de la salle.

### 3.1. Spacialisation

Nous aimerions étudier la faisabilité d’un système de tuyaux et de pavillons pouvant acheminer et spacialiser des sources sonores produites acoustiquement dans la remorque : voix humaine, instrument, grammophone, etc.

### 3.2. Effet d’infra-basses

Pour reproduire les sensations physiques éprouvées dans une salle de cinéma, nous imaginons pouvoir faire « vibrer » les sièges à la façon d’un subwoofer. À étudier le faisabilité d’une vibration produite par frottement d’une came dentelée contre une butée, transmise de façon solidienne aux sièges des spectateurs, eux-mêmes fixés sur silent-blocs.

### 3.3. Isolation sonore

Conjointement aux soucis d’isolation thermique évoqués plus haut, il semble important pour l’immersion que les spectateurs soient un minimum protégé du bruit exterieur surtout que le spectacle sera surtout joué dans des environnements urbrains (voitures, passants, etc.).

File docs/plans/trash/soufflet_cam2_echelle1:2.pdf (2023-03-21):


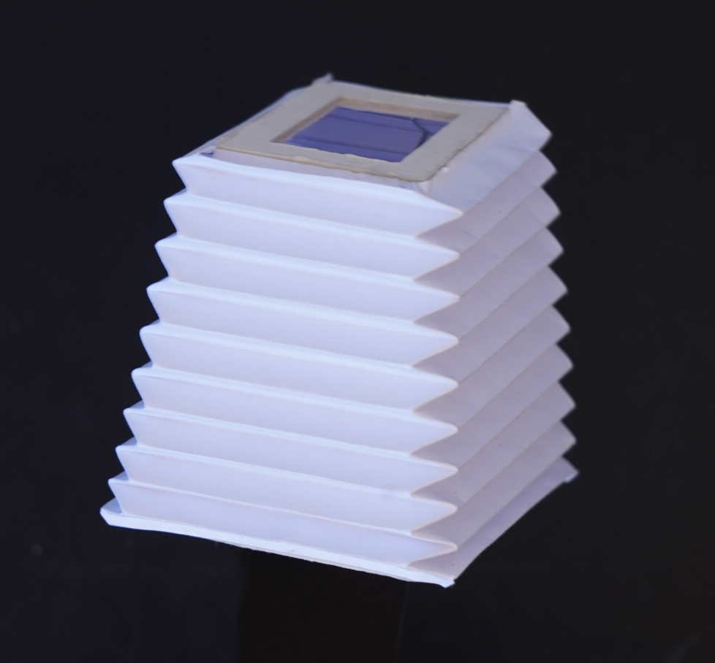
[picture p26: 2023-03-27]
contenu/photos/maquette_soufflet.jpg

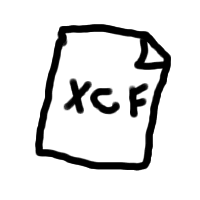
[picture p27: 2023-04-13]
assets/img/file.xcf.png

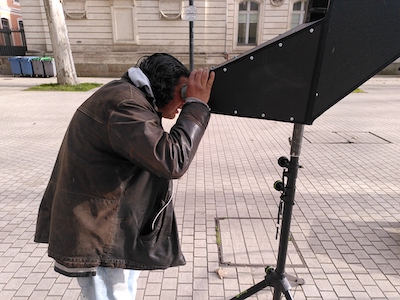
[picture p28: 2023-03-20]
contenu/photos/les_yeux_dans_le_dos_7.jpg

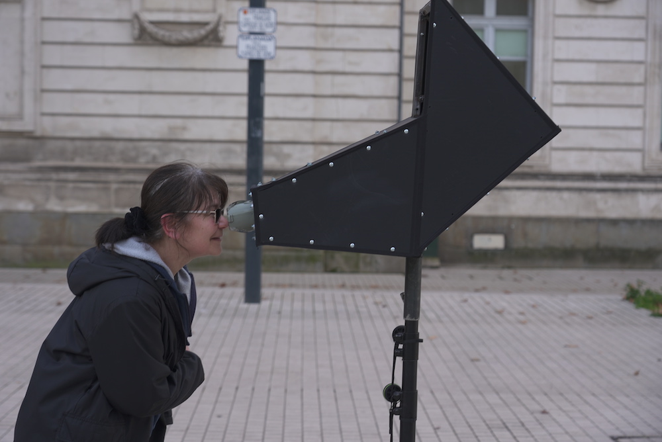
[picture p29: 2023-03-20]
docs/photos/les_yeux_dans_le_dos_6_light.JPG

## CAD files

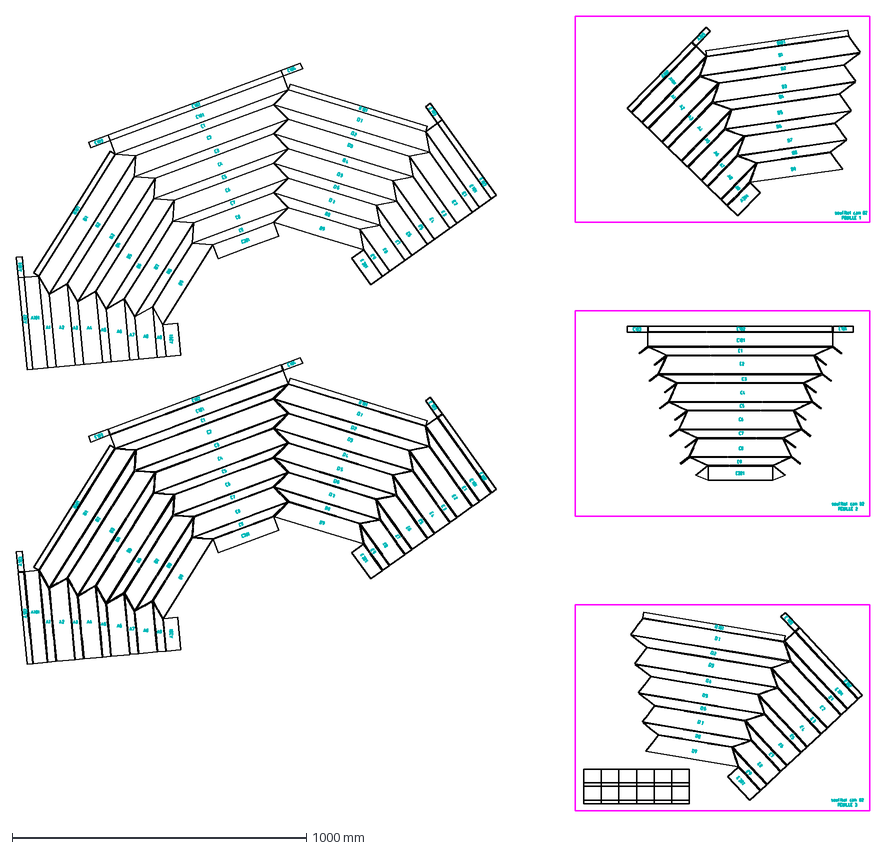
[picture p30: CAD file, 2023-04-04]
contenu/plans/soufflet-cam02.dxf
2899.0 x 2700.0 mm

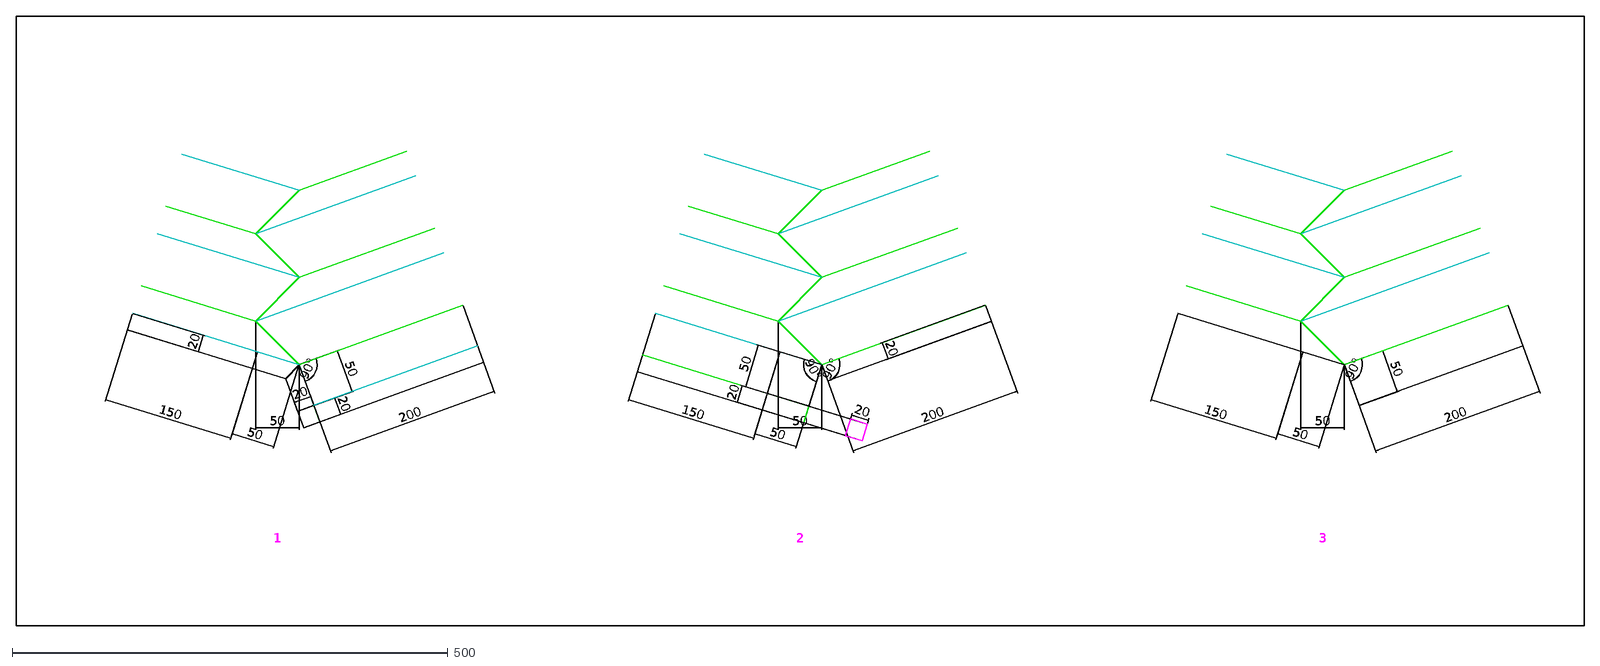
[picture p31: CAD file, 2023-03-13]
docs/plans/collage-soufflet-patrons.dxf
90°
50
150
200
20
1
2
3

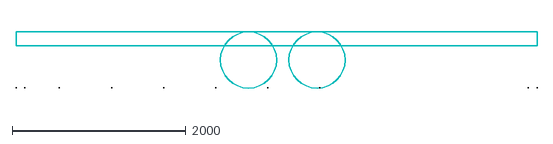
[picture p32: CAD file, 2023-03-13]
docs/plans/remorque.dxf
6000.0 x 648.0

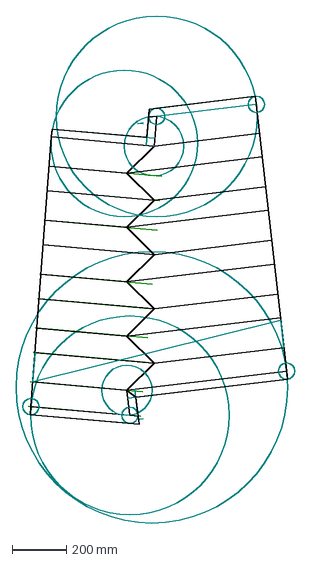
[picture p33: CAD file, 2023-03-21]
docs/plans/trash/patron soufflet.dxf
1026.4 x 1868.2 mm

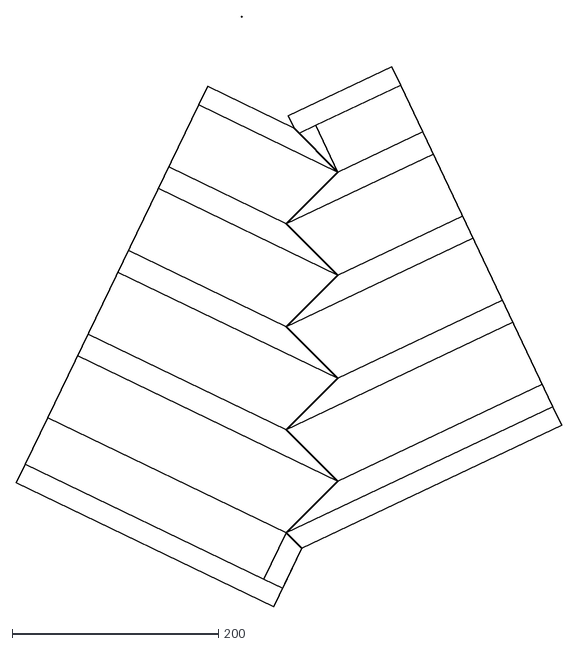
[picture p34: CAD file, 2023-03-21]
docs/plans/trash/patron soufflet cam2.dxf
528.9 x 572.8

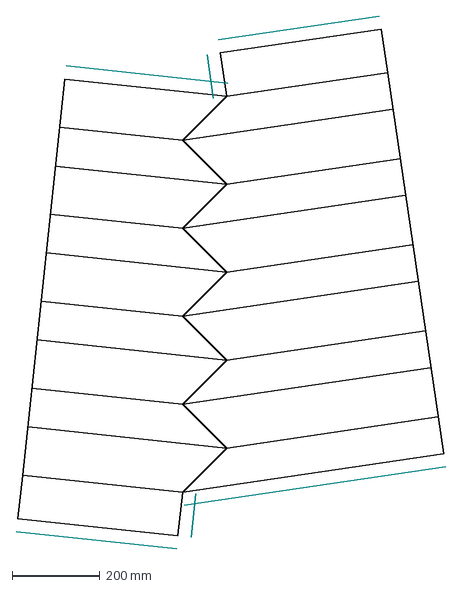
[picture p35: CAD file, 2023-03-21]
docs/plans/trash/soufflet cam3 1.dxf
975.7 x 1211.8 mm

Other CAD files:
docs/plans/trash/soufflet_cam_2.dxf
contenu/plans/soufflet-cam03-B.dxf
contenu/plans/soufflet-cam03-A.dxf

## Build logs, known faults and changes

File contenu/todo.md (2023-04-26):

# TODO

### Production

- Relance courrier partenaires avec dossier + lien du site

### Courses

AVANT RESIDENCE QUAI 9/5/2023
- bache pour le camion
- 1 miroir ultra clair pour essais double-image et essai 2D

### Construction

AVANT RESIDENCE QUAI 9/5/2023
- Renforcer les soufflets (3h)
- Fixation chassis au camion (equerre à fixer sur la taule)
- Tailler/Fixer bache pour le camion. (+ aimants)
- Concevoir Porte-planchette pour le grand soufflet. (plusieurs objectifs)
- Fabriquer planchettes pour les differents objectifs et lentilles.
- Avancer sur les plans de la remorque.
- Rendez-vous Arnaud pour conseils construction remorque

APRÈS RESIDENCE QUAI 9/5/2023
- réparer gramophone

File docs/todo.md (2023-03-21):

- Rendez-vous Arnaud pour conceils construction remorque

- compléter documentation

- mail Vincent avec README protos

- relance courrier avec dossier

- commande conex cornière et grenouillères

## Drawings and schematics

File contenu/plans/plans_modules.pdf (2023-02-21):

# Prismes modulaires - Camera obscura - Cie NOKILL

## 1:10 (1mm = 1cm)

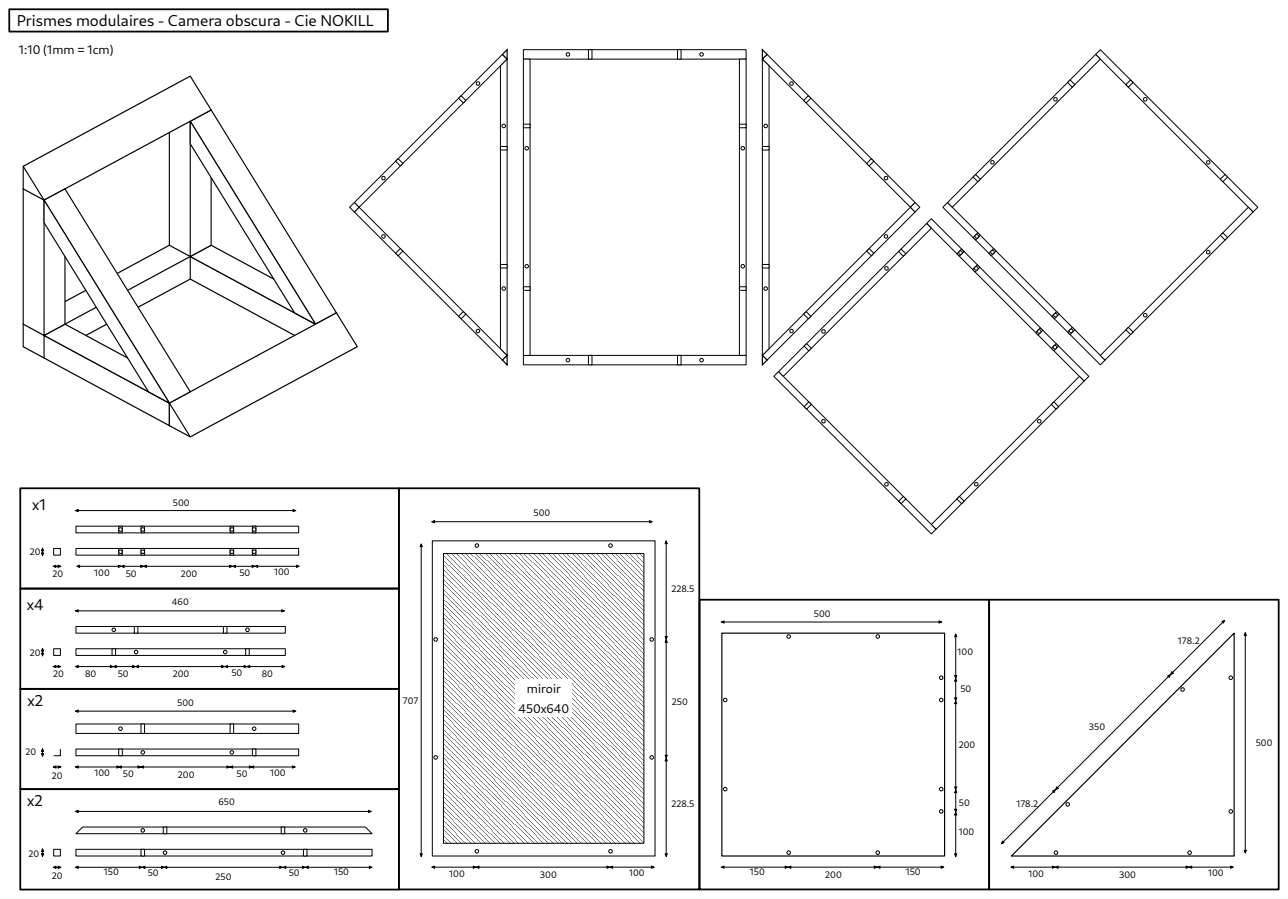
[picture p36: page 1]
miroir 450x640

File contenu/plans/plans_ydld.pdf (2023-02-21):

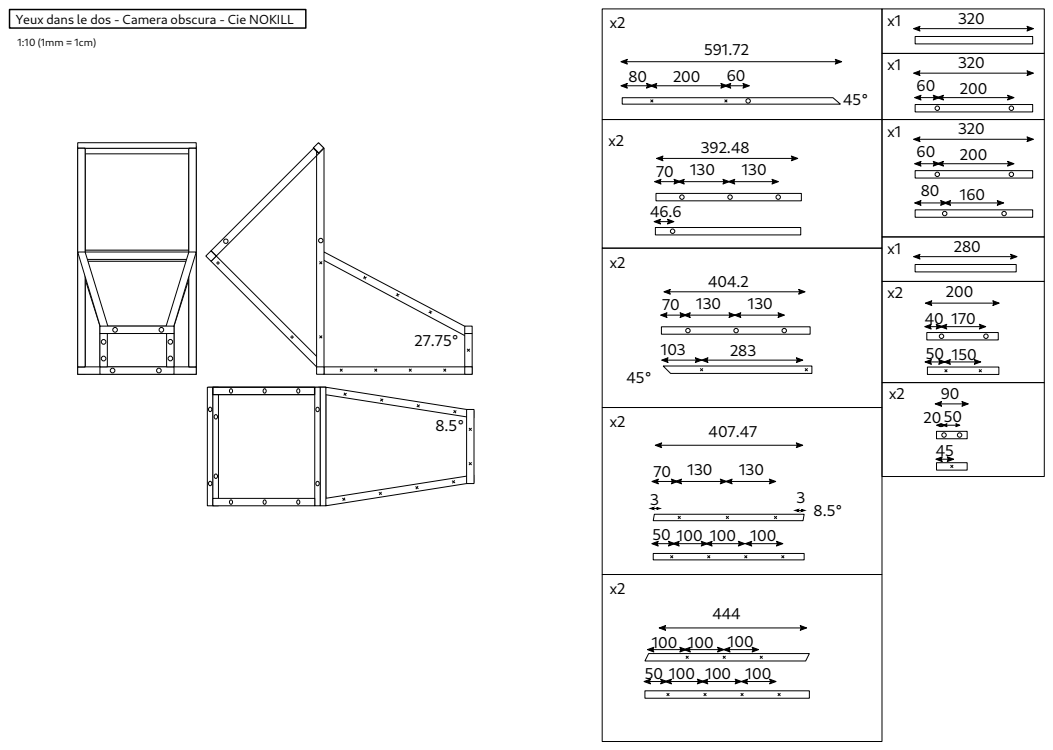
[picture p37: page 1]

Yeux dans le dos - Camera obscura - Cie NOKILL

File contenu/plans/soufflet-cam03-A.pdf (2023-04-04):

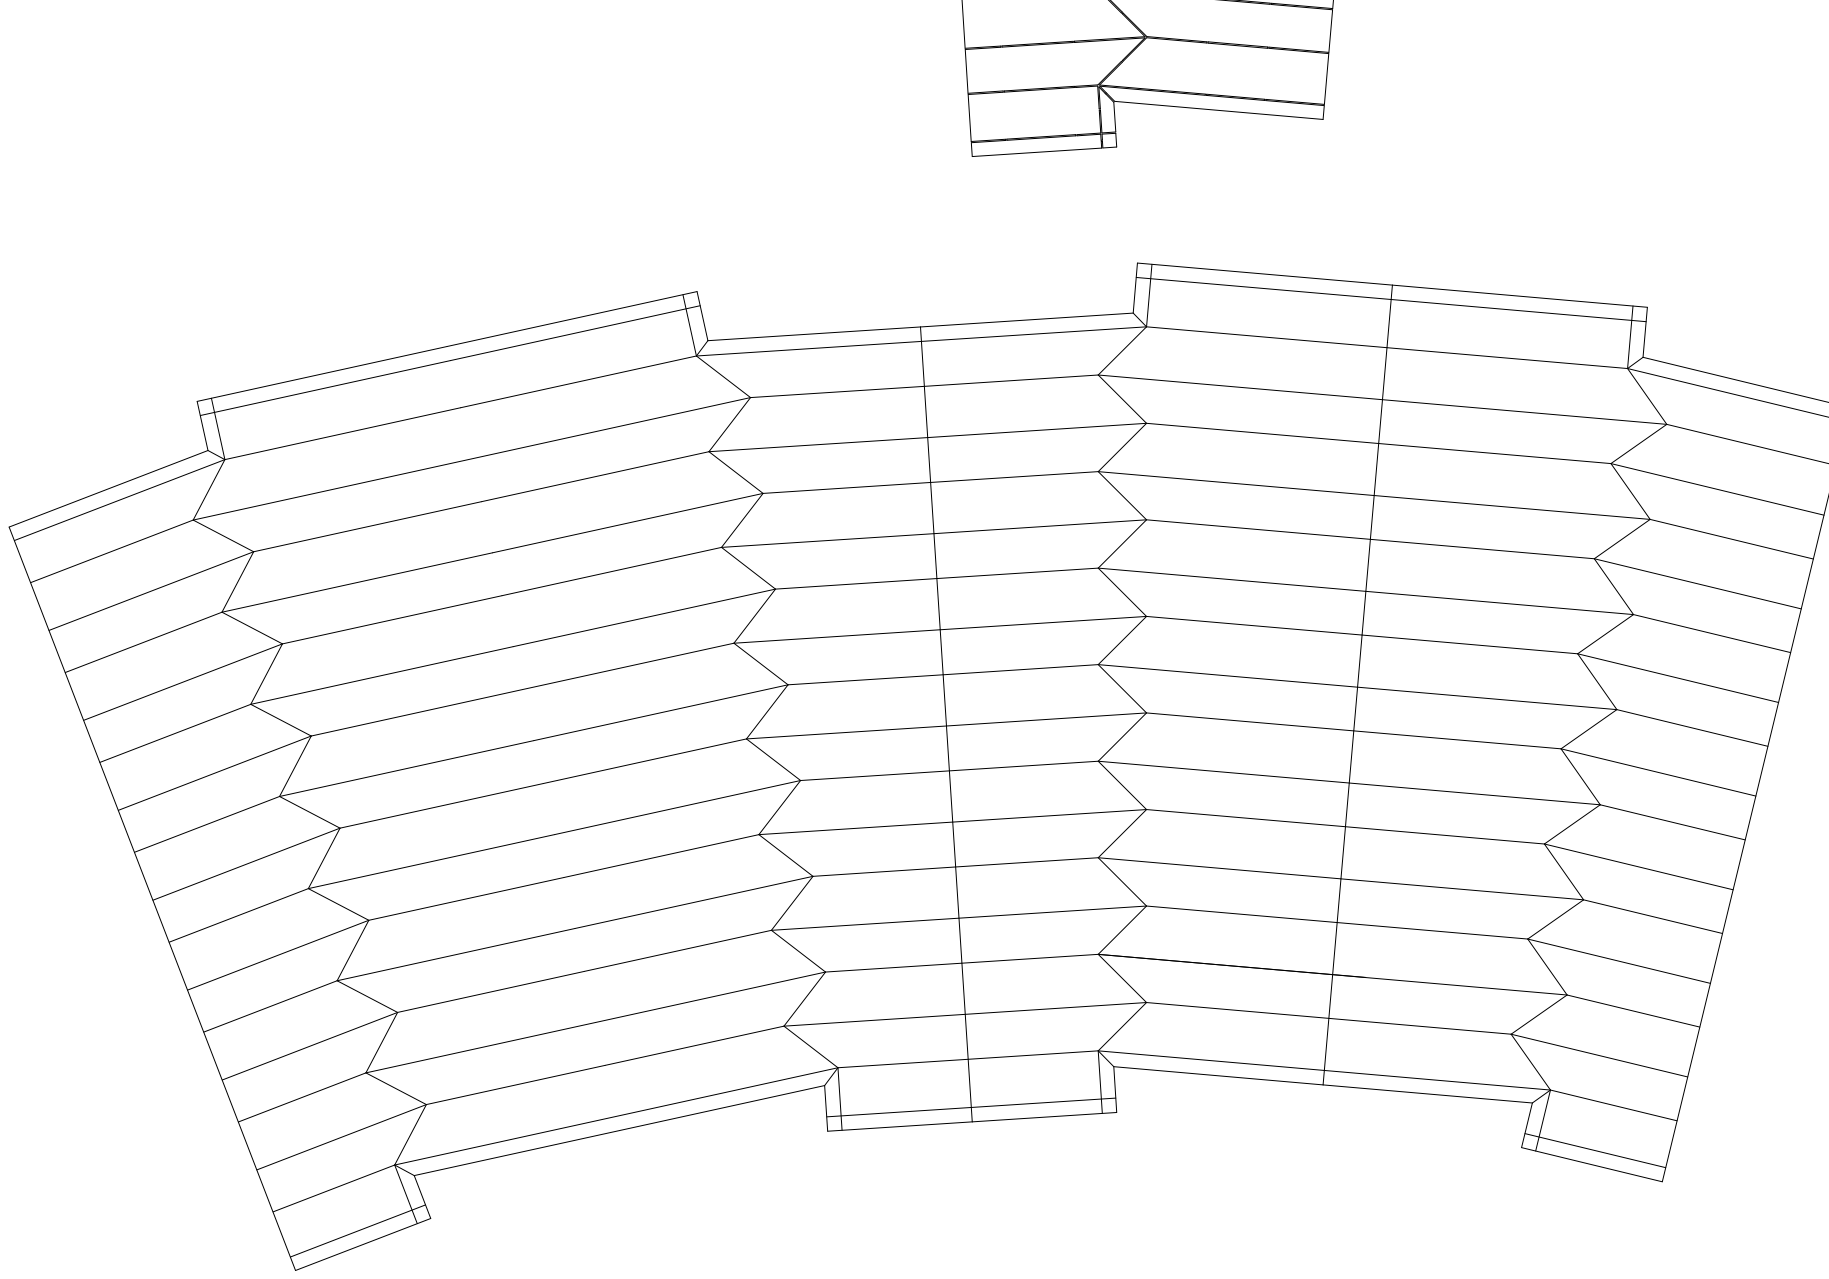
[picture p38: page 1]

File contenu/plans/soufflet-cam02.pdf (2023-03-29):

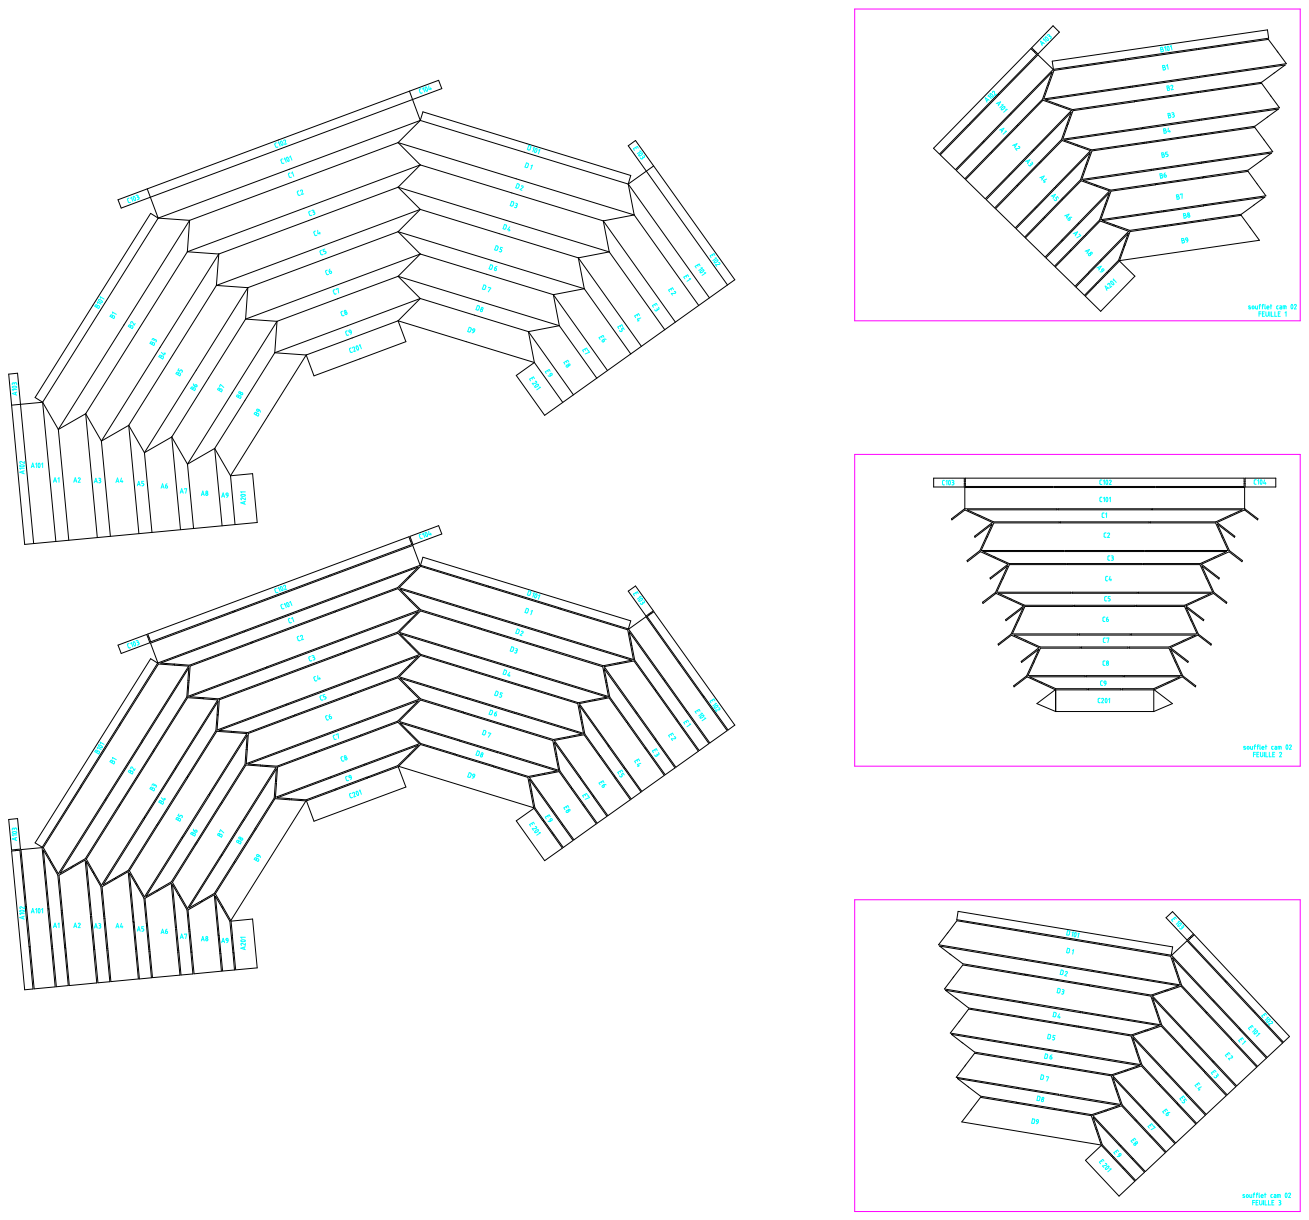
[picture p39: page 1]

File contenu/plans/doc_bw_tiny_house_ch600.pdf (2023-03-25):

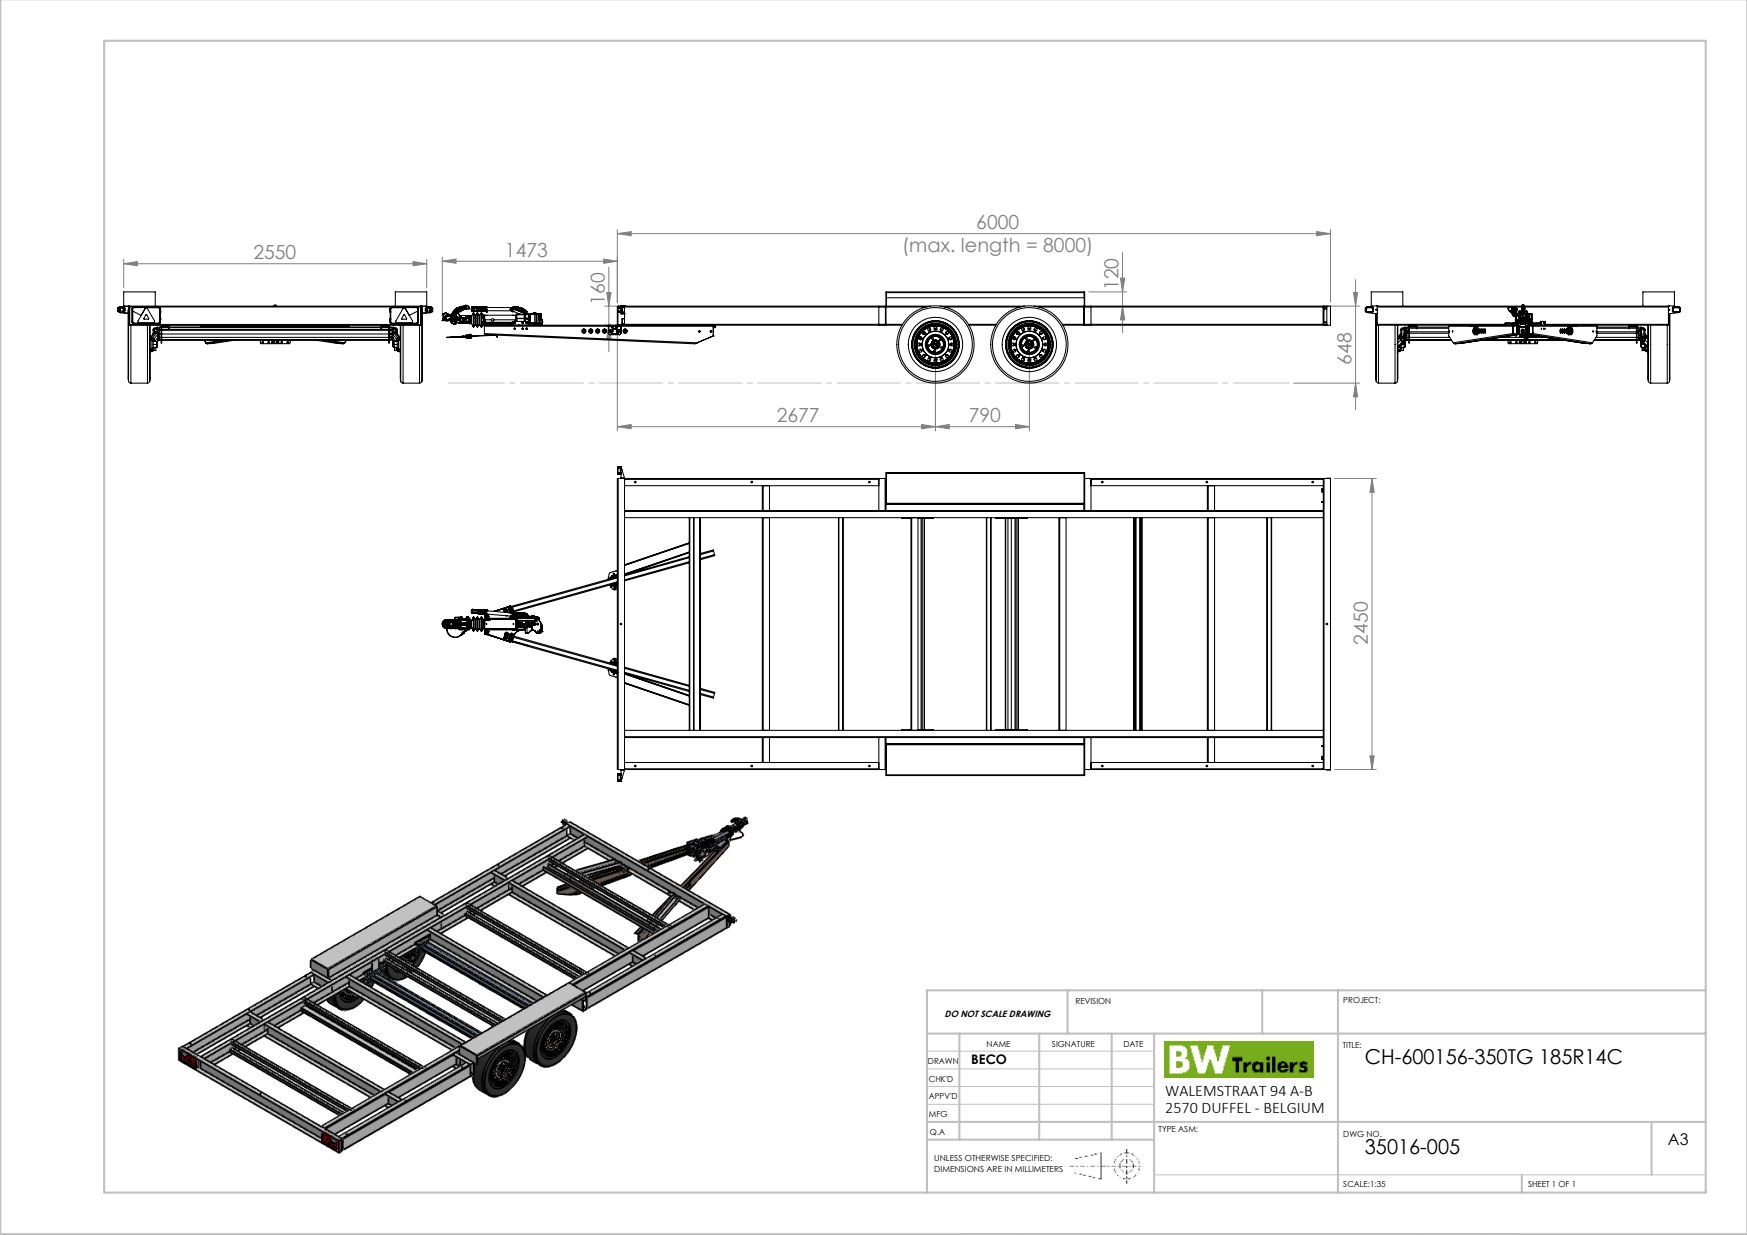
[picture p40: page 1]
(max. length = 8000) 1473; SCALE:1:35; SHEET 1 OF 1; PROJECT:; C:\Users\Bert.BWTRAILERS0\Desktop\1 ONTWERPEN\1.4

DO NOT SCALE DRAWING | REVISION
NAME | SIGNATURE | DATE | WALEMSTRAAT 94 A-B 2570 DUFFEL - BELGIUM | TITLE: CH-600156-350TG 185R14C

DRAWN | BECO

CHK'D
APPV'D
MFG
Q.A | | | | TYPE ASM: | DWG NO. 35016-005 | A3

UNLESS OTHERWISE SPECIFIED:
DIMENSIONS ARE IN MILLIMETERS

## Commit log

2023-03-13 plans et soufflets
    [collage-soufflet-patrons.dxf, remorque.dxf]
2023-03-21 restructuration site
    [collage-soufflet-patrons.dxf, patron soufflet cam2.dxf, patron soufflet.dxf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]
2023-03-21 titres prototypes
2023-03-23 ré-réorga
    [collage-soufflet-patrons.dxf, patron soufflet cam2.dxf, patron soufflet.dxf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]
2023-03-29 soufflet ok pour fablab
    [soufflet-cam02.dxf]
2023-04-13 reorganisation medias
    [patron soufflet cam2.dxf, patron soufflet.dxf, soufflet cam3 1.dxf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]
